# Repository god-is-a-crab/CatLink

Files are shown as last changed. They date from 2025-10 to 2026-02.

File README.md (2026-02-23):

# CatLink
This is a GPS tracking solution for cats.

## Overview

There are 3 components of the CatLink system:

- Tracker (collar) - This device tracks the animal's position
- Gateway - This device manages communication with the tracker and the user's phone
- CatLink app - Displays animal position, radio link quality and other information

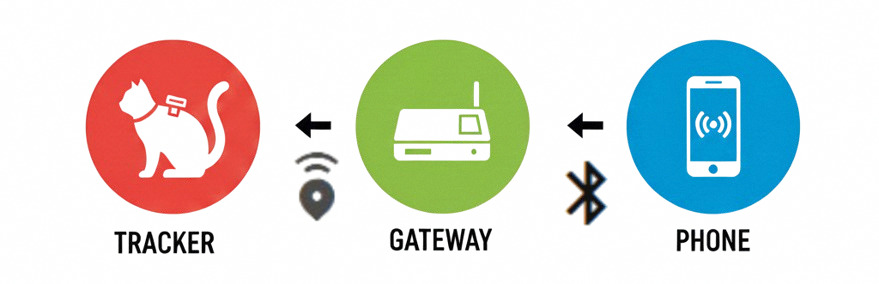
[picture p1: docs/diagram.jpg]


## Bluetooth Bonding
1. Open the app
2. When it tries to connect to the gateway, it will ask for a passkey to bond
3. Enter the number written on the gateway case
4. Close the app and open it again, the bluetooth connect button should show a green check mark

## How to use

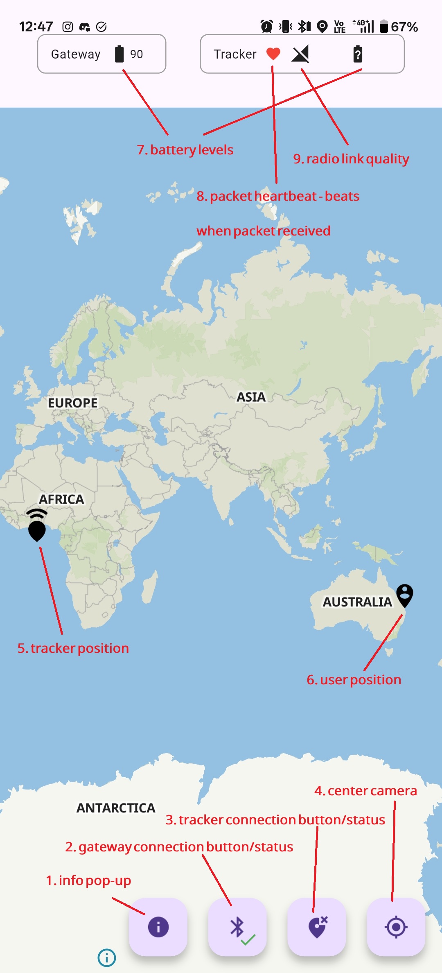
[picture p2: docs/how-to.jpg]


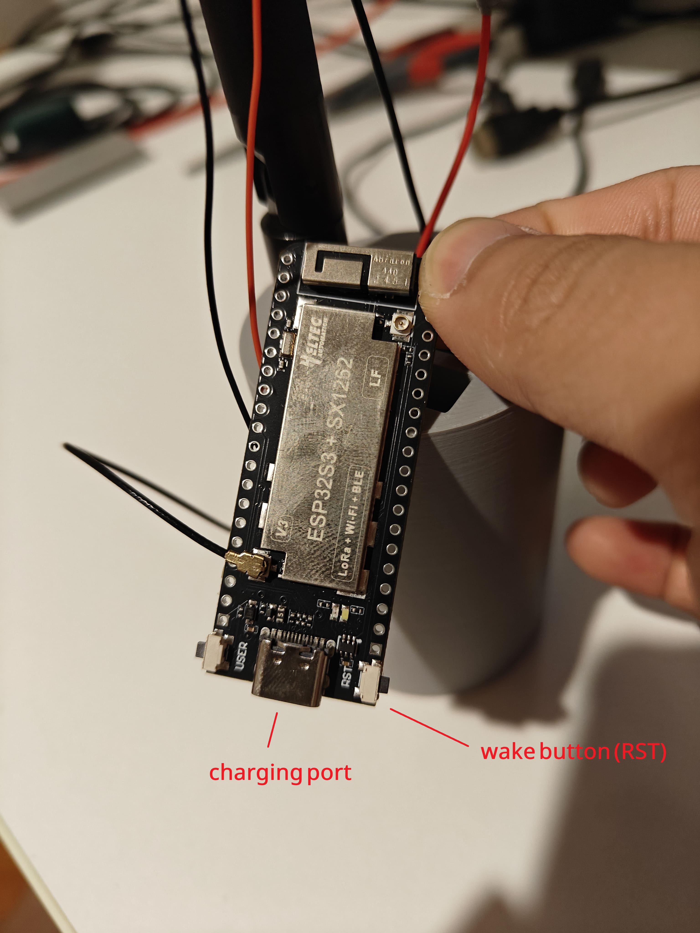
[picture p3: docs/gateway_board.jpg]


1. Wake up the gateway using the RST button, a white LED will flash to indicate the gateway is pending connection
2. On your phone, turn on location services and open the app
3. Monitor the bluetooth button (number 2 in image), wait for a green check mark to show
4. Press the tracker connect button (number 3 in image), wait for green check mark
5. Wait for tracker position marker (number 5 in image) to update
6. Monitor heartbeat symbol (number 8 in image) to confirm tracker is communicating

## Images

### Collar
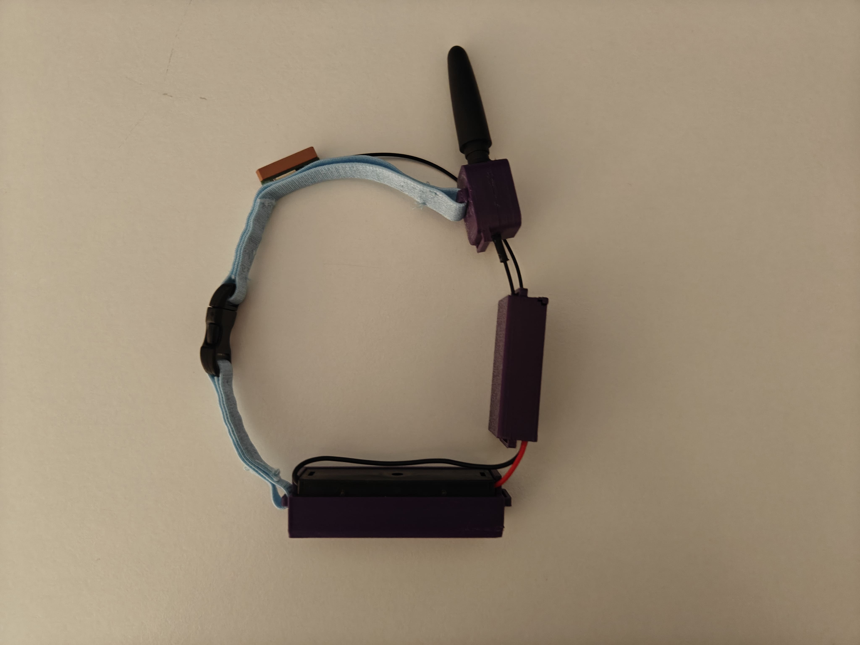
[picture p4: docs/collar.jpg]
collar


### Gateway
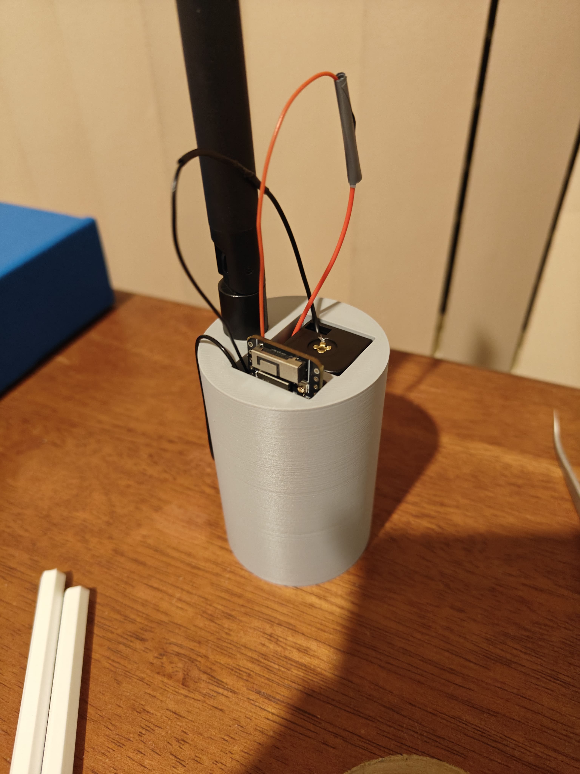
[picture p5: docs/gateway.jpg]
gateway


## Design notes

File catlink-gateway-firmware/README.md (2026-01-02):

## CatLink Gateway Firmware

CatLink gateway device which manages a LoRa connection to the tracker. Gateway is controlled by the app.

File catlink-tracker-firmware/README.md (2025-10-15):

# CatLink Tracker
This is a device that transmits GNSS position data to a receiver using an SX1268 LoRA module. It is optimized for low-power consumption.

## Pins
| IO Pin | MCU Function | Module Function |
|---|---|---|
| A0 | ADC1 C5 | Battery VIN |
| A2 | Output open-drain | Battery voltage divider switch |
| A4 | SPI1 NSS | LoRA NSS |
| A5 | SPI1 SCK | LoRA SCK |
| A6 | SPI1 MISO | LoRA MISO |
| A7 | SPI1 MOSI | LoRA MOSI |
| A15 | Input EXTI15_10 | DIO3 |
| B3 | Output | GNSS ON/OFF |
| B4 | Input EXTI4 | DIO1 |
| B5 | Input | GNSS 1PPS |
| B6 | USART1 TX | GNSS RX |
| B7 | USART1 RX | GNSS TX |

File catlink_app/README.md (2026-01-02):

# catlink_app

A mobile app to control the CatLink Gateway.

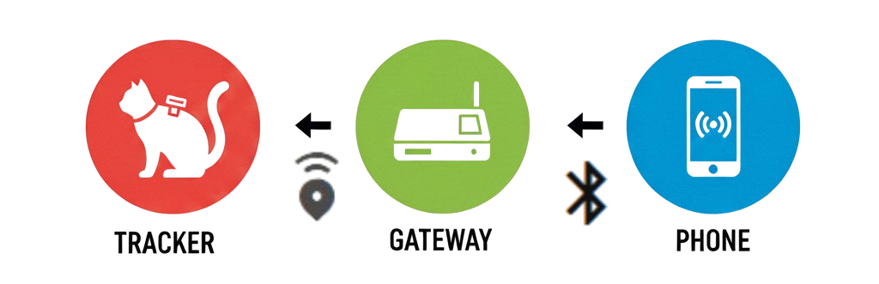
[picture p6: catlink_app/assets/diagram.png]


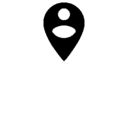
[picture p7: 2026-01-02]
catlink_app/assets/user_marker.png

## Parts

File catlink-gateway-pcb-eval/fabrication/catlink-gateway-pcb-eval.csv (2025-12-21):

Reference | Qty | Value | Footprint
BT1 | 1 | 18650 | Custom:BatteryHolder_Keystone_1042_1x18650
C1,C13 | 2 | 100n | Capacitor_SMD:C_0603_1608Metric
C2,C4,C6,C7,C8,C10,C11,C12 | 8 | 10u | Capacitor_SMD:C_0805_2012Metric
C3,C5,C9 | 3 | 1u | Capacitor_SMD:C_0603_1608Metric
D1,D2,D5 | 3 | ESD5Z6.0T1G | Diode_SMD:D_SOD-523
D3,D6 | 2 | GREEN | LED_SMD:LED_0805_2012Metric
D4,D8 | 2 | RED | LED_SMD:LED_0805_2012Metric
D7 | 1 | TPD1E0B04DPY | Custom:D_Texas_DPY0002A_0.6x1mm_P0.65mm
J1 | 1 | TYPE-C-31-M-12 | Connector_USB:USB_C_Receptacle_HRO_TYPE-C-31-M-12
J2,J3 | 2 | Conn_02x05_Odd_Even | Connector_PinHeader_2.54mm:PinHeader_2x05_P2.54mm_Vertical
R1,R2,R3,R9,R13,R14,R17,R22,R23 | 9 | 10k | Resistor_SMD:R_0603_1608Metric
R4,R5 | 2 | 22 | Custom:R_0603_1608Metric
R6,R7 | 2 | 5k1 | Resistor_SMD:R_0603_1608Metric
R8 | 1 | 400m | Resistor_SMD:R_1206_3216Metric
R10,R11,R12,R20,R21 | 5 | 1k2 | Resistor_SMD:R_0603_1608Metric
R15,R16,R19 | 3 | 330k | Resistor_SMD:R_0603_1608Metric
R18 | 1 | 1M5 | Resistor_SMD:R_0603_1608Metric
SW1,SW2 | 2 | SW_SPDT | Button_Switch_THT:SW_Slide_SPDT_Angled_CK_OS102011MA1Q
U1 | 1 | ESP32-C3-MINI-1 | Custom:ESP32-C3-MINI-1
U2 | 1 | TPD4E05U06DQA | Package_SON:USON-10_2.5x1.0mm_P0.5mm
U3 | 1 | TP4056-42-ESOP8 | Package_SO:SOIC-8-1EP_3.9x4.9mm_P1.27mm_EP2.41x3.3mm
U4 | 1 | TPS2116DRL | Package_TO_SOT_SMD:SOT-583-8
U5 | 1 | TLV75901PDRV | Package_SON:WSON-6-1EP_2x2mm_P0.65mm_EP1x1.6mm
U6 | 1 | Ai-Thinker-Ra-01S | Custom:Ai-Thinker-Ra-01S

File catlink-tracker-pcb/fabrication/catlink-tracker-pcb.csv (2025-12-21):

Reference | Qty | Value | Footprint
C1 | 1 | 4u7 | Custom:C_0603_1608Metric
C2,C3,C6,C10,C12,C13 | 6 | 100n | Custom:C_0603_1608Metric
C4 | 1 | 10n | Custom:C_0603_1608Metric
C5,C7,C8 | 3 | 1u | Custom:C_0603_1608Metric
C9,C11 | 2 | 10u | Custom:C_0805_2012Metric
C14 | 1 | 100p | Custom:C_0603_1608Metric
D1 | 1 | ESD5Z6.0T1G | Custom:D_SOD-523
D2,D3 | 2 | TPD1E0B04DPY | Custom:D_Texas_DPY0002A_0.6x1mm_P0.65mm
J1 | 1 | S2B-PH-K | Connector_JST:JST_PH_S2B-PH-K_1x02_P2.00mm_Horizontal
J2 | 1 | U.FL | Connector_Coaxial:U.FL_Hirose_U.FL-R-SMT-1_Vertical
L1 | 1 | 82n | Custom:L_0603_1608Metric
R1,R2,R3,R4 | 4 | 10k | Custom:R_0603_1608Metric
R5,R6 | 2 | 100r | Custom:R_0603_1608Metric
TP1,TP2,TP3 | 3 | TestPoint | Custom:TestPoint_THT_D1.4mm_Drill0.8mm
U1 | 1 | STM32L412K8Tx | Custom:LQFP-32_7x7mm_P0.8mm
U2 | 1 | TLV75530PDBV | Custom:SOT-23-5
U3 | 1 | Ai-Thinker-Ra-01S | Custom:Ai-Thinker-Ra-01S
U4 | 1 | E108-GN03 | Custom:E108-GN03

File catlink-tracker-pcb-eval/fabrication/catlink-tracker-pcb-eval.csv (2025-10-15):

Id | Designator | Footprint | Quantity | Designation | Supplier and ref
1 | D2,D3 | D_Texas_DPY0002A_0.6x1mm_P0.65mm | 2 | TPD1E0B04DPY
2 | C8,C7,C5 | C_0603_1608Metric | 3 | 1u
3 | C9,C11 | C_0805_2012Metric | 2 | 10u
4 | C10,C3,C2,C13,C12,C6 | C_0603_1608Metric | 6 | 100n
5 | U2 | SOT-23-5 | 1 | TLV75530PDBV
6 | D1 | D_SOD-523 | 1 | ESD5Z6.0T1G
7 | U3 | Ai-Thinker-Ra-01S | 1 | Ai-Thinker-Ra-01S
8 | J4 | PinHeader_2x02_P2.54mm_Vertical | 1 | Header_02x02
9 | U4 | E108-GN03 | 1 | E108-GN03
10 | R3,R4,R2,R1 | R_0603_1608Metric | 4 | 10k
11 | L1 | L_0603_1608Metric | 1 | 82n
12 | J1 | JST_PH_S2B-PH-K_1x02_P2.00mm_Horizontal | 1 | S2B-PH-K
13 | J2 | U.FL_Hirose_U.FL-R-SMT-1_Vertical | 1 | U.FL
14 | C14 | C_0603_1608Metric | 1 | 100p
15 | C4 | C_0603_1608Metric | 1 | 10n
16 | R5,R6 | R_0603_1608Metric | 2 | 100r
17 | J8 | PinHeader_1x05_P2.54mm_Vertical | 1 | Header_01x05
18 | R8,R7 | R_Axial_DIN0204_L3.6mm_D1.6mm_P1.90mm_Vertical | 2 | 2k
19 | C1 | C_0603_1608Metric | 1 | 4u7
20 | D5 | LED_D3.0mm | 1 | RED
21 | D4 | LED_D3.0mm | 1 | BLUE
22 | J6 | PinHeader_1x02_P2.54mm_Vertical | 1 | Header_01x02
23 | J3 | PinHeader_1x04_P2.54mm_Vertical | 1 | Header_01x03
24 | J7 | PinHeader_1x06_P2.54mm_Vertical | 1 | Header_01x06
25 | U1 | LQFP-32_7x7mm_P0.8mm | 1 | STM32L412K8Tx
26 | J5 | PinHeader_2x03_P2.54mm_Vertical | 1 | Header_02x03
27 | SW1 | SW_PUSH_5x7mm | 1 | SW_Push

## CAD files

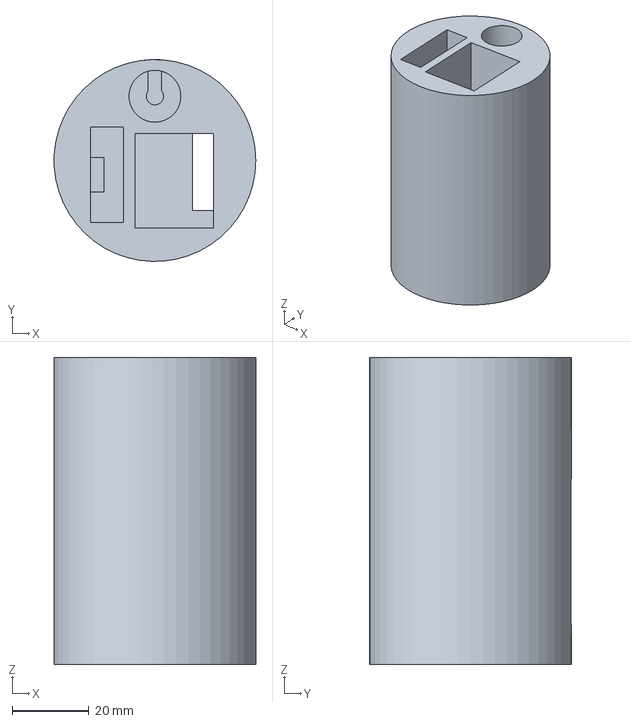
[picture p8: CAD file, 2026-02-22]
enclosures/gateway.FCStd
52.6 x 52.6 x 80.0 mm

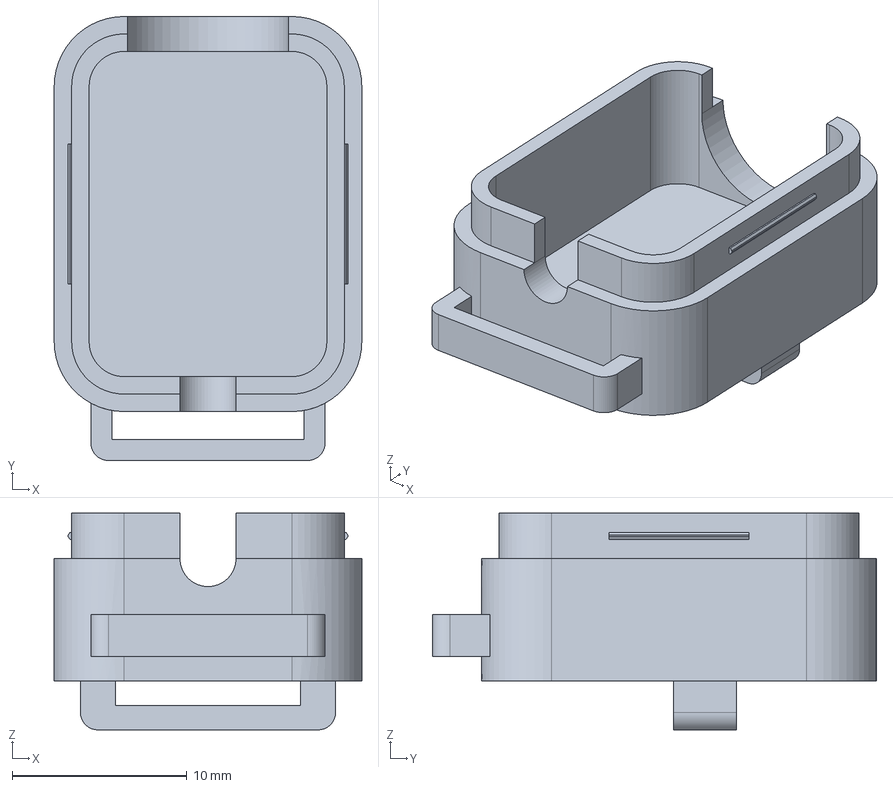
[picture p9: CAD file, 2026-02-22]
enclosures/lora_antenna.FCStd
17.6 x 25.4 x 12.4 mm

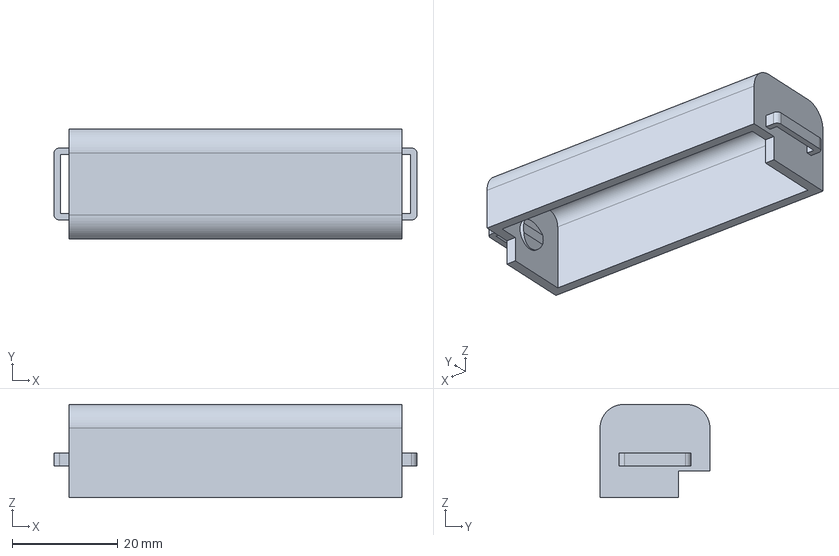
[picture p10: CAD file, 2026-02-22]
enclosures/battery14500.FCStd
68.6 x 20.8 x 17.6 mm

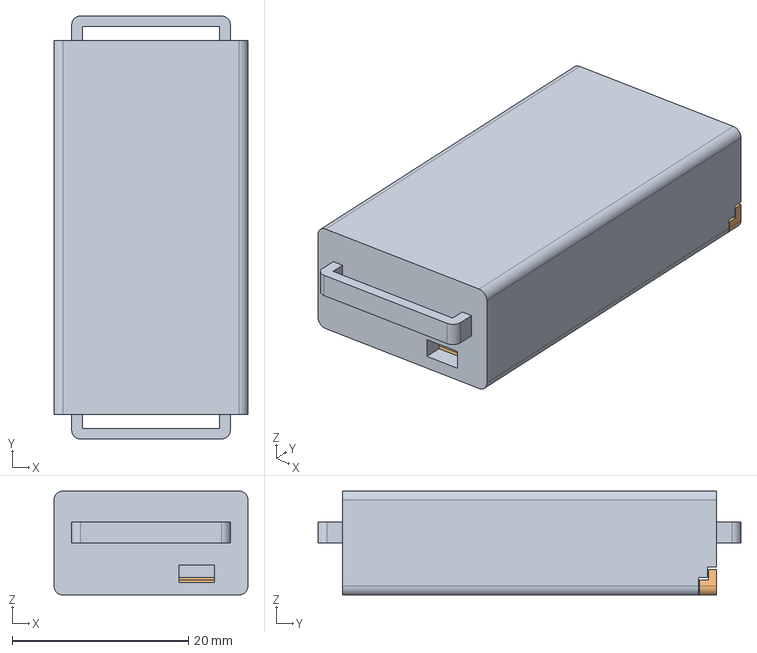
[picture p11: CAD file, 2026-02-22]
enclosures/pcb.FCStd
22.0 x 48.0 x 11.8 mm
enclosure
lid

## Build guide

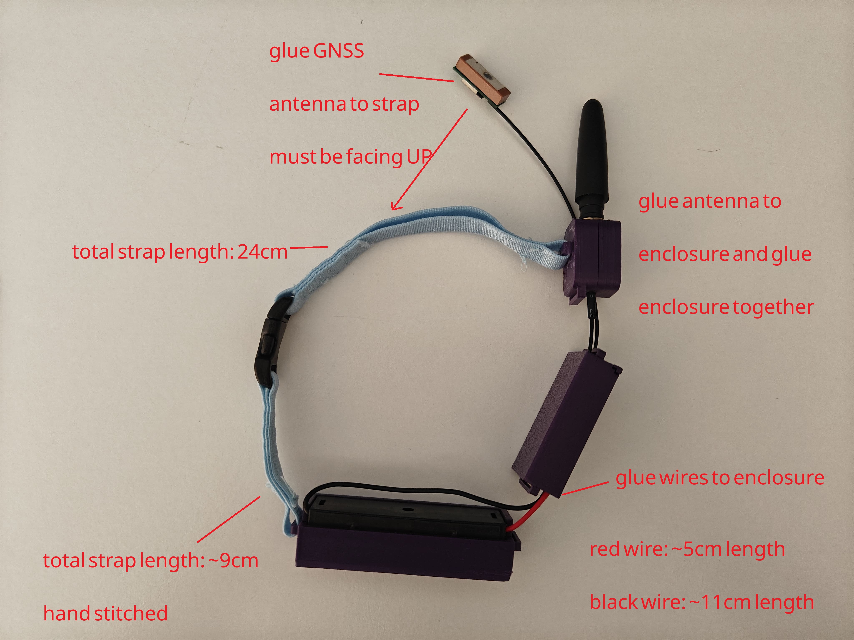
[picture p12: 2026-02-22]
docs/collar_assembly.jpg

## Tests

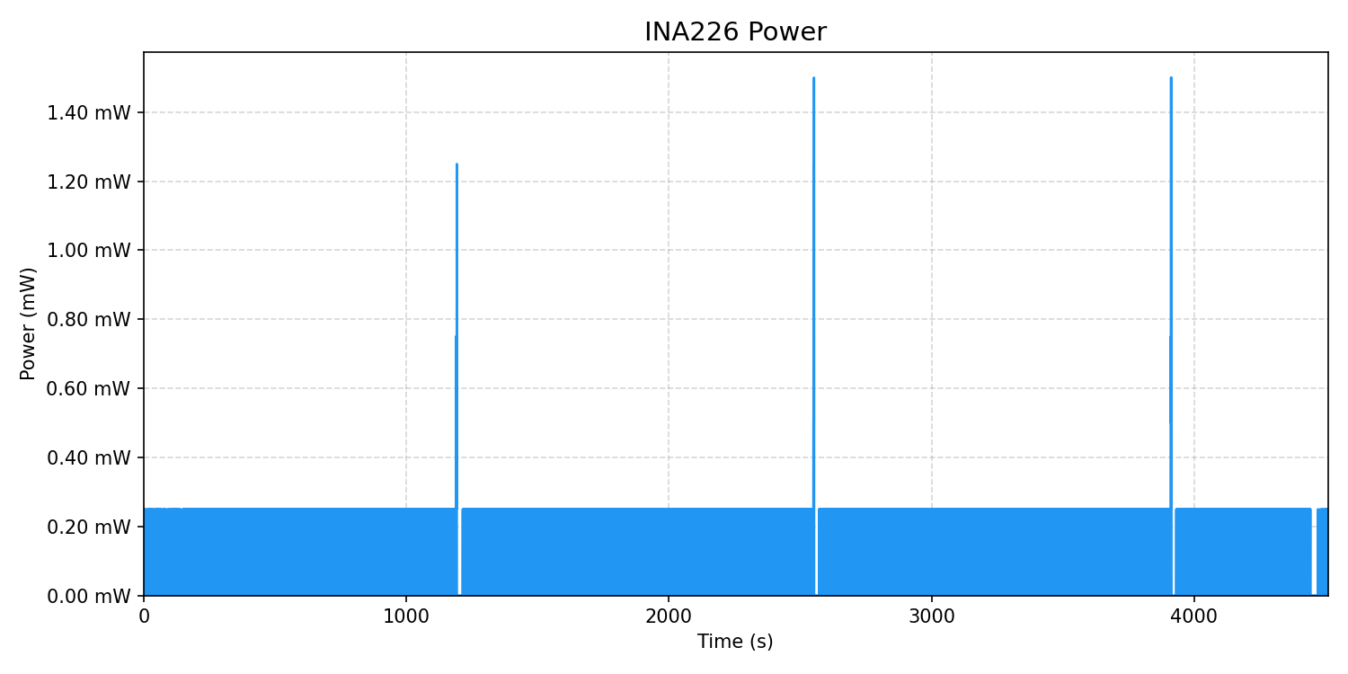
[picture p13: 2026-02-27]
power-measurement/v0.1-eval_sleep.png

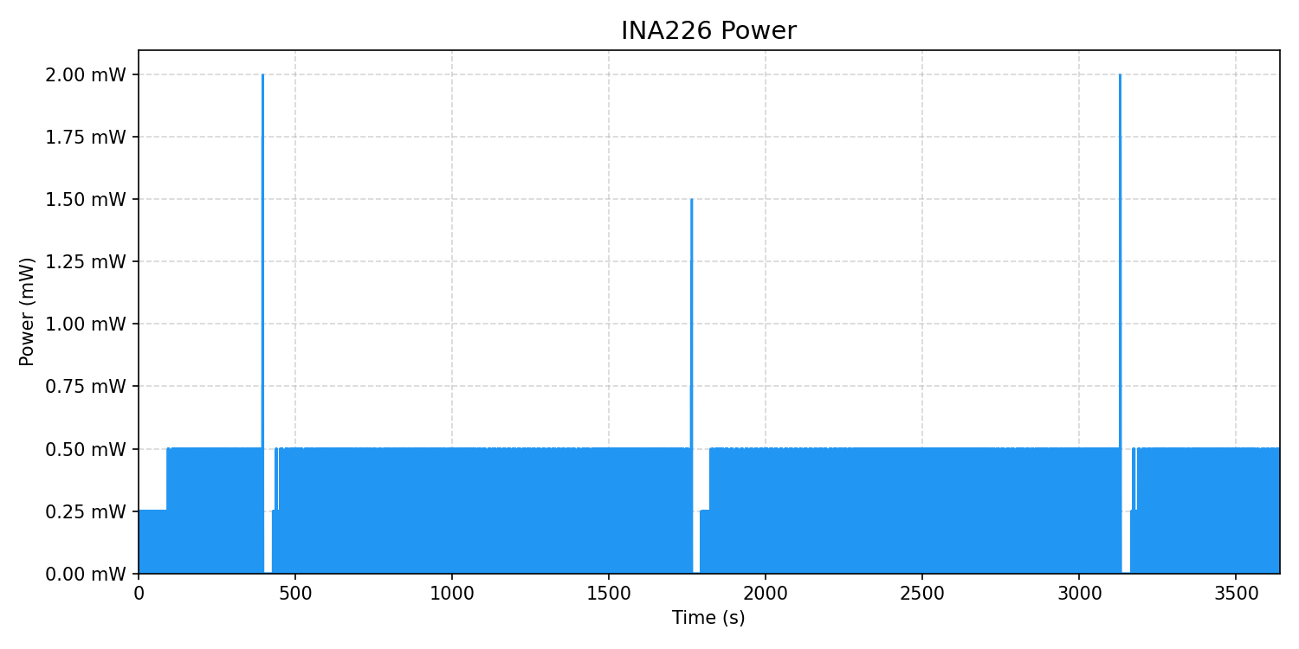
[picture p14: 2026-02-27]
power-measurement/v0.2-eval_sleep.png

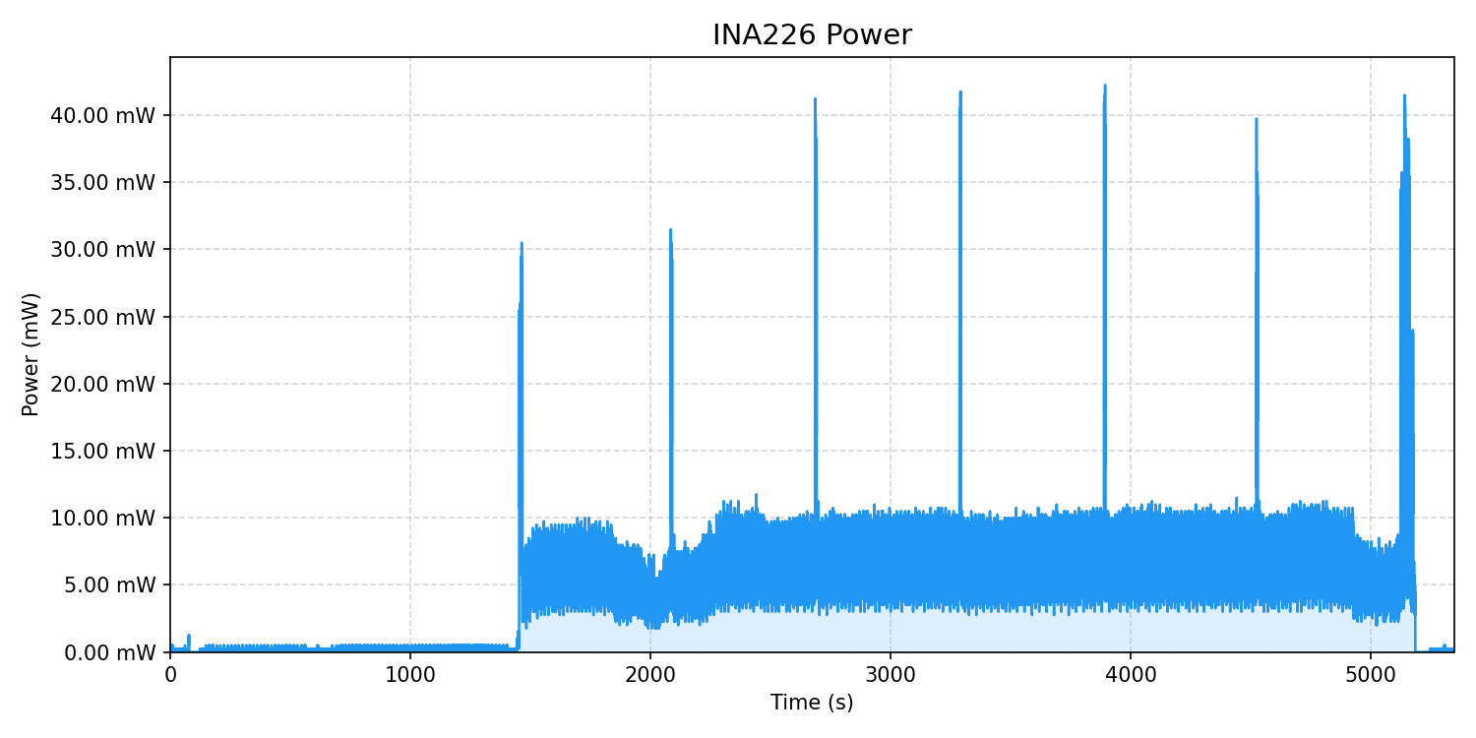
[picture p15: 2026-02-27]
power-measurement/v0.2-eval_tracking.png

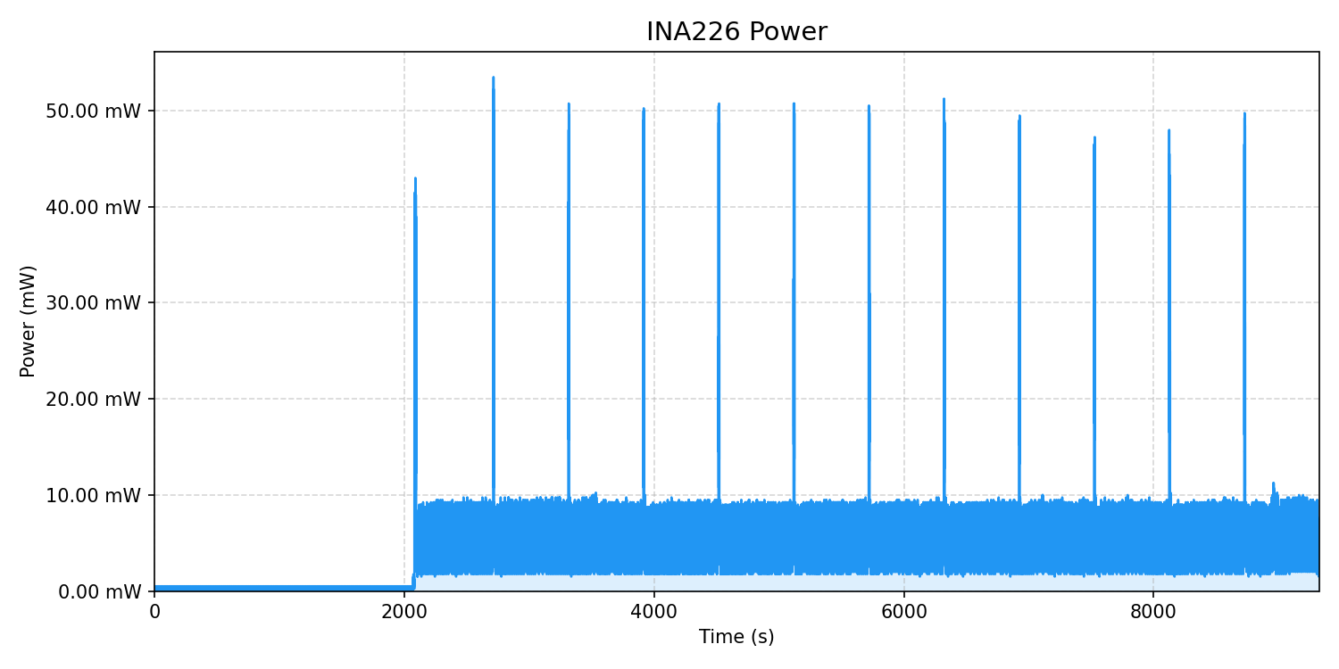
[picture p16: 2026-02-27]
power-measurement/prod_tracking_nofix.png

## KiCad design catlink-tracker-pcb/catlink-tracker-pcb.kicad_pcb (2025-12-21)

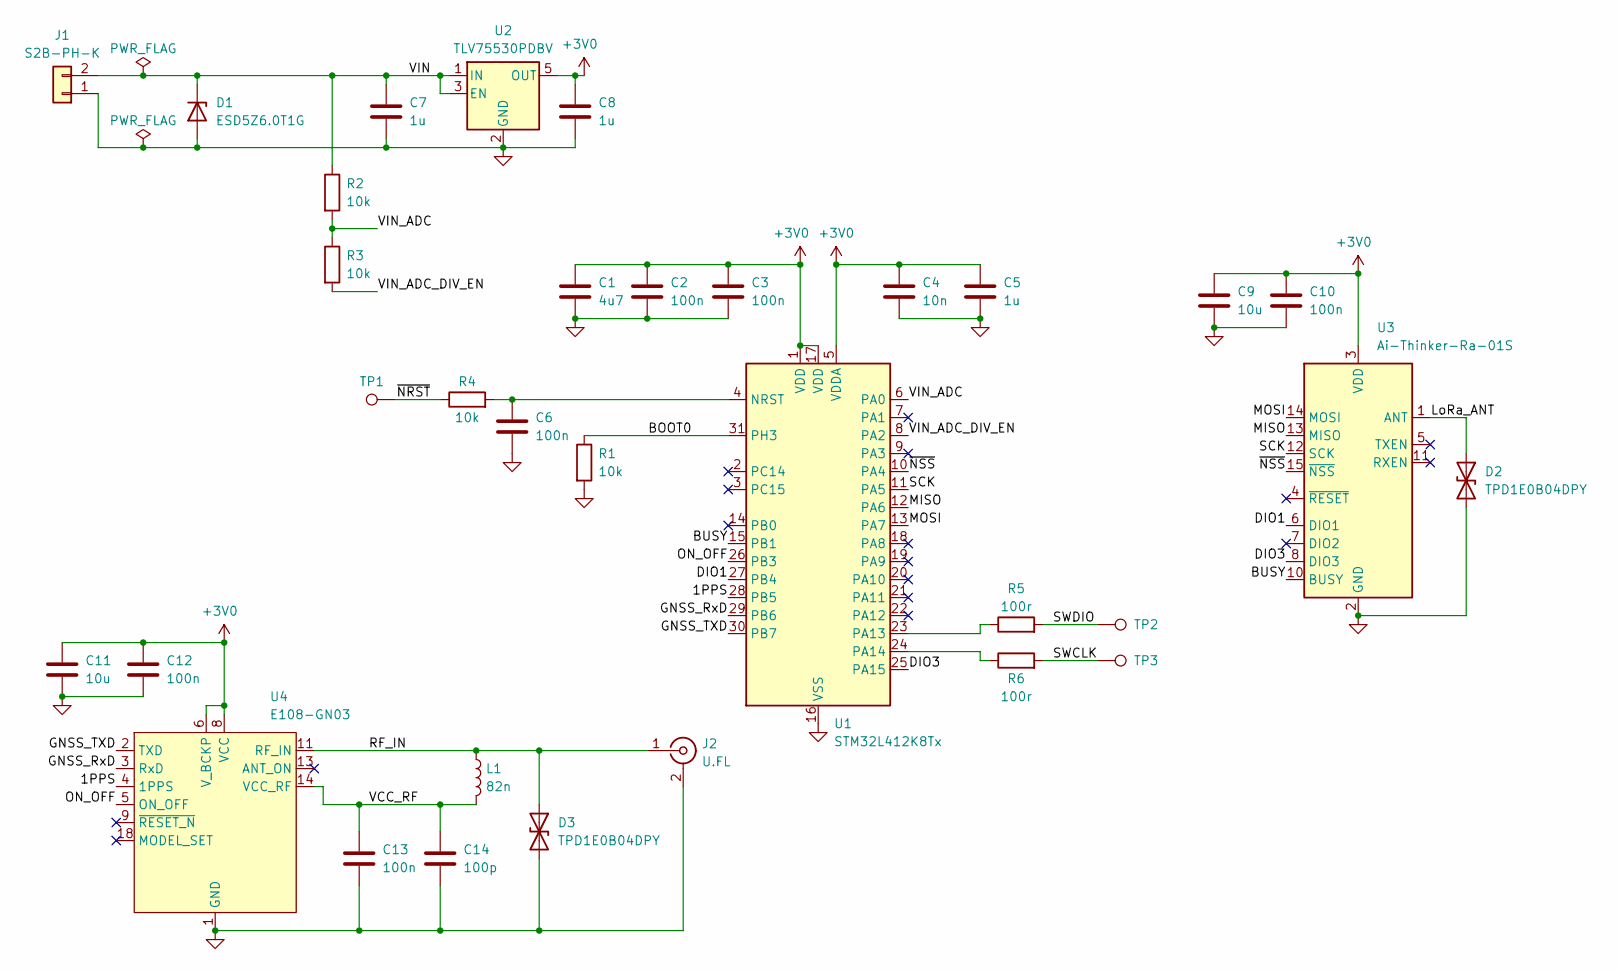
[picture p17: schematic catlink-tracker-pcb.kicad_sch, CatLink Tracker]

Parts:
C1: 4u7; C_0603_1608Metric
C2, C3, C6, C10, C12, C13: 100n; C_0603_1608Metric
C4: 10n; C_0603_1608Metric
C5, C7, C8: 1u; C_0603_1608Metric
C9, C11: 10u; C_0805_2012Metric
C14: 100p; C_0603_1608Metric
D1: ESD5Z6.0T1G; D_SOD-523
D2, D3: TPD1E0B04DPY; D_Texas_DPY0002A_0.6x1mm_P0.65mm
J1: S2B-PH-K; JST_PH_S2B-PH-K_1x02_P2.00mm_Horizontal
J2: U.FL; U.FL_Hirose_U.FL-R-SMT-1_Vertical
L1: 82n; L_0603_1608Metric
R1, R2, R3, R4: 10k; R_0603_1608Metric
R5, R6: 100r; R_0603_1608Metric
TP1, TP2, TP3: TestPoint; TestPoint_THT_D1.4mm_Drill0.8mm
U1: STM32L412K8Tx; LQFP-32_7x7mm_P0.8mm
U2: TLV75530PDBV; SOT-23-5
U3: Ai-Thinker-Ra-01S
U4: E108-GN03

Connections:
+3V0: C1.1, C2.1, C3.1, C4.1, C5.1, C8.1, C9.1, C10.1, C11.1, C12.1, U1.1 (VDD), U1.5 (VDDA), U1.17 (VDD), U2.5 (OUT), U3.3 (VDD), U4.6 (V_BCKP), U4.8 (VCC)
/1PPS: U1.28 (PB5), U4.4 (1PPS)
/BOOT0: R1.1, U1.31 (PH3)
/BUSY: U1.15 (PB1), U3.10 (BUSY)
/DIO1: U1.27 (PB4), U3.6 (DIO1)
/DIO3: U1.25 (PA15), U3.8 (DIO3)
/GNSS_RxD: U1.29 (PB6), U4.3 (RxD)
/GNSS_TXD: U1.30 (PB7), U4.2 (TXD)
/LoRa_ANT: D2.1 (A1), U3.1 (ANT)
/MISO: U1.12 (PA6), U3.13 (MISO)
/MOSI: U1.13 (PA7), U3.14 (MOSI)
/ON_OFF: U1.26 (PB3), U4.5 (ON_OFF)
/RF_IN: D3.1 (A1), J2.1 (In), L1.1, U4.11 (RF_IN)
/SCK: U1.11 (PA5), U3.12 (SCK)
/SWCLK: R6.2, TP3.1
/SWDIO: R5.2, TP2.1
/VCC_RF: C13.1, C14.1, L1.2, U4.14 (VCC_RF)
/VIN: C7.1, D1.1 (K), J1.2, R2.1, U2.1 (IN), U2.3 (EN)
/VIN_ADC: R2.2, R3.1, U1.6 (PA0)
/VIN_ADC_DIV_EN: R3.2, U1.8 (PA2)
/~NRST: R4.1, TP1.1
/~NSS: U1.10 (PA4), U3.15 (~NSS)
GND: C1.2, C2.2, C3.2, C4.2, C5.2, C6.2, C7.2, C8.2, C9.2, C10.2, C11.2, C12.2, C13.2, C14.2, D1.2 (A), D2.2 (A2), D3.2 (A2), J1.1, J2.2 (Ext), R1.2, U1.16 (VSS), U1.32 (VSS), U2.2 (GND), U3.2 (GND), U3.9 (GND), U3.16 (GND), U4.1 (GND), U4.10 (GND), U4.12 (GND)
unnamed: C6.1, R4.2, U1.4 (NRST)
unnamed: R5.1, U1.23 (PA13)
unnamed: R6.1, U1.24 (PA14)

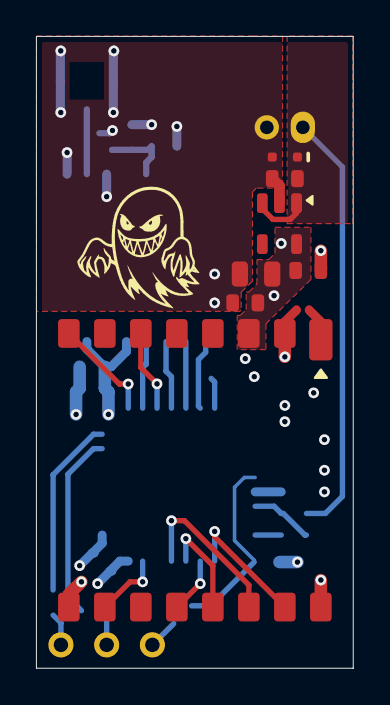
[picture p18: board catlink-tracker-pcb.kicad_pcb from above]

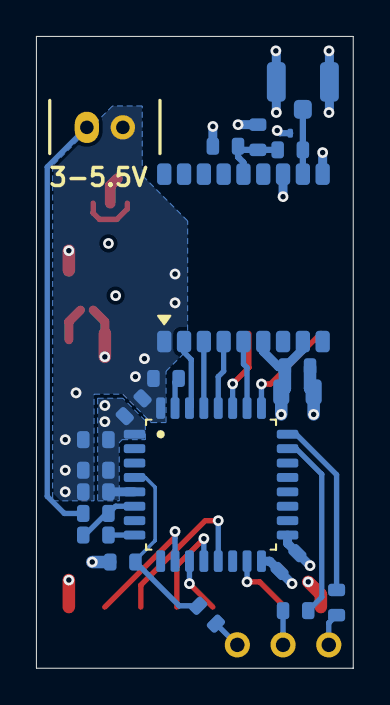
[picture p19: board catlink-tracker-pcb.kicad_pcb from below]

Board: 4 copper layers, 17.6 x 35.1 mm, 33 parts (25 on the bottom side), 26 nets.

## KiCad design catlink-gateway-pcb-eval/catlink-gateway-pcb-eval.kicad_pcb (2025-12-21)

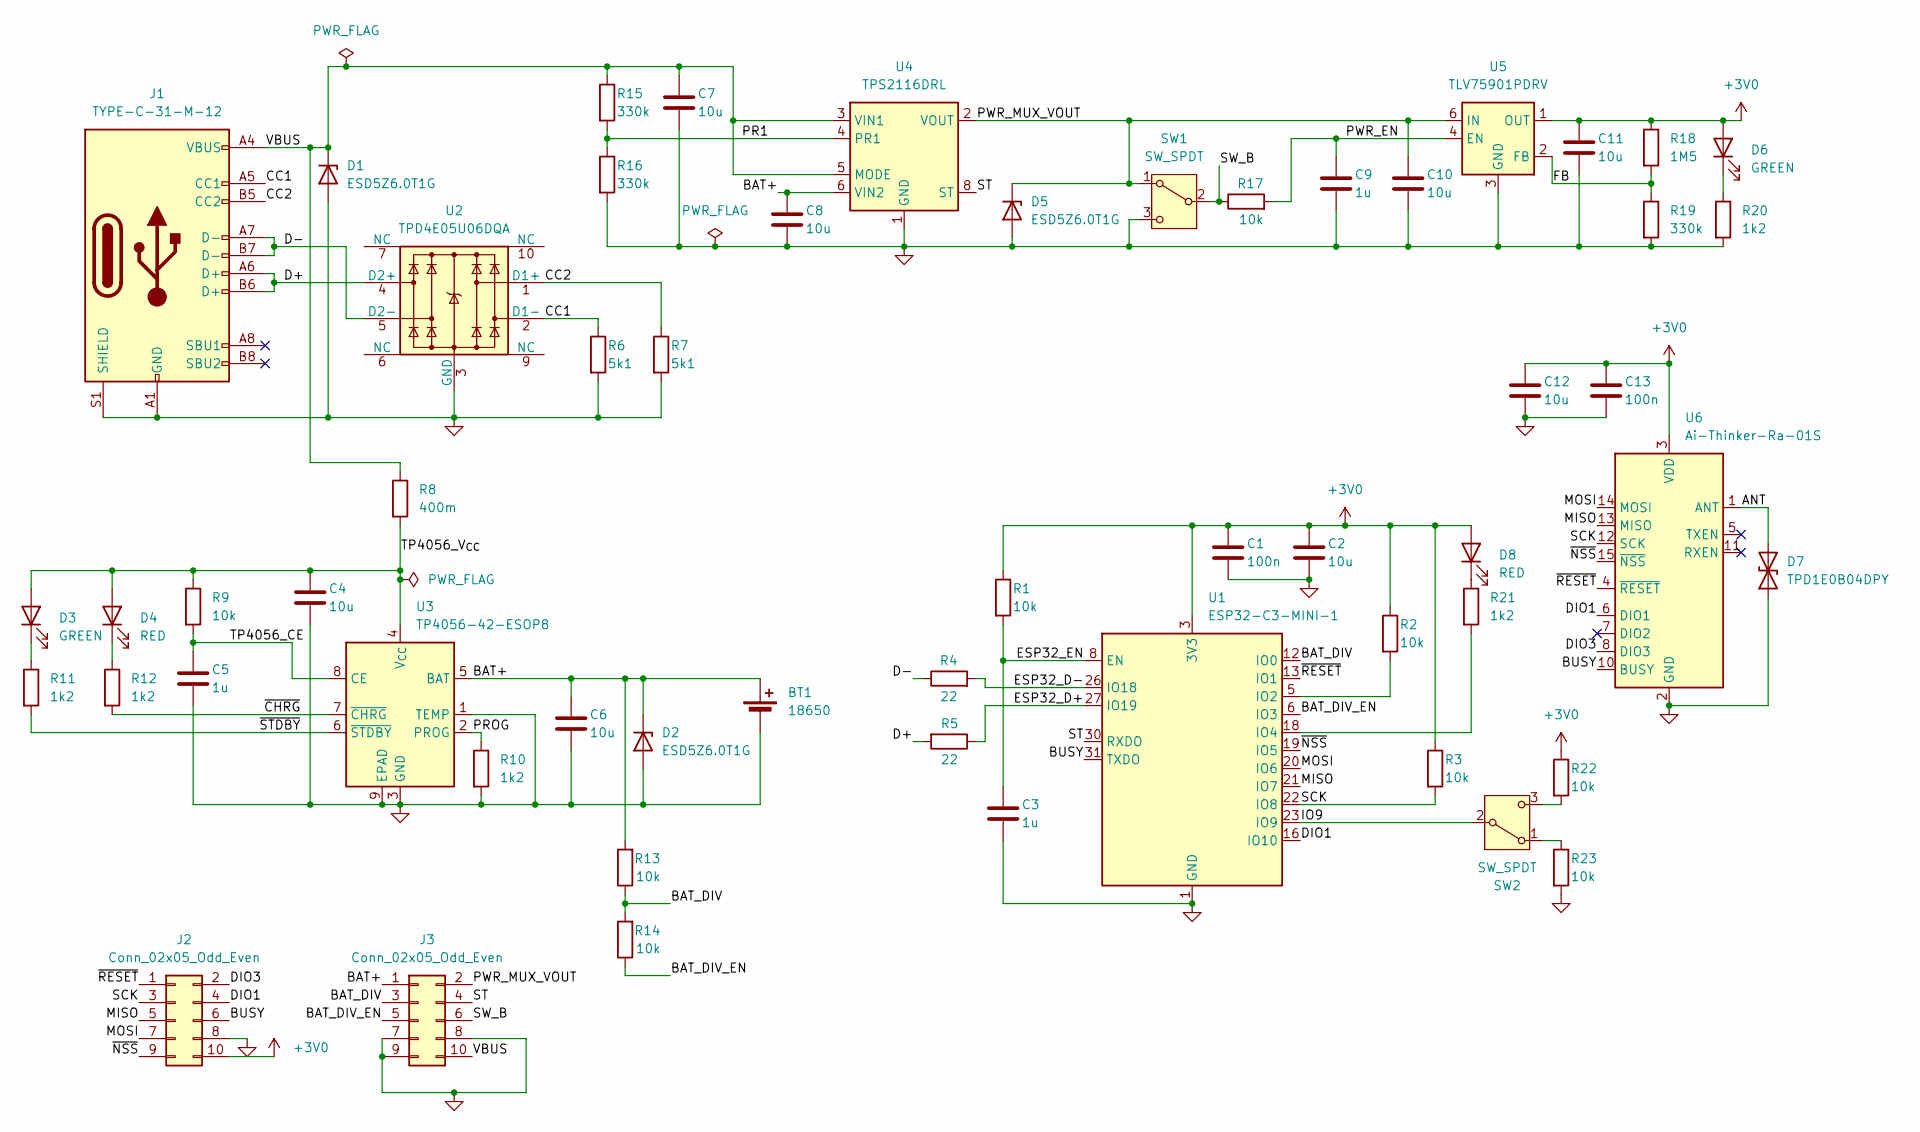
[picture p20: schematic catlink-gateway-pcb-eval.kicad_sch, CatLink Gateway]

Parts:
BT1: 18650; BatteryHolder_Keystone_1042_1x18650
C1, C13: 100n; C_0603_1608Metric
C2, C4, C6, C7, C8, C10, C11, C12: 10u; C_0805_2012Metric
C3, C5, C9: 1u; C_0603_1608Metric
D1, D2, D5: ESD5Z6.0T1G; D_SOD-523
D3, D6: GREEN; LED_0805_2012Metric
D4, D8: RED; LED_0805_2012Metric
D7: TPD1E0B04DPY; D_Texas_DPY0002A_0.6x1mm_P0.65mm
J1: TYPE-C-31-M-12; USB_C_Receptacle_HRO_TYPE-C-31-M-12
J2, J3: Conn_02x05_Odd_Even; PinHeader_2x05_P2.54mm_Vertical
R1, R2, R3, R9, R13, R14, R17, R22, R23: 10k; R_0603_1608Metric
R4, R5: 22; R_0603_1608Metric
R6, R7: 5k1; R_0603_1608Metric
R8: 400m; R_1206_3216Metric
R10, R11, R12, R20, R21: 1k2; R_0603_1608Metric
R15, R16, R19: 330k; R_0603_1608Metric
R18: 1M5; R_0603_1608Metric
SW1, SW2: SW_SPDT; SW_Slide_SPDT_Angled_CK_OS102011MA1Q
U1: ESP32-C3-MINI-1
U2: TPD4E05U06DQA; USON-10_2.5x1.0mm_P0.5mm
U3: TP4056-42-ESOP8; SOIC-8-1EP_3.9x4.9mm_P1.27mm_EP2.41x3.3mm
U4: TPS2116DRL; SOT-583-8
U5: TLV75901PDRV; WSON-6-1EP_2x2mm_P0.65mm_EP1x1.6mm
U6: Ai-Thinker-Ra-01S

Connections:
+3V0: C1.1, C2.1, C11.1, C12.1, C13.1, D6.2 (A), D8.2 (A), J2.10, R1.1, R2.1, R3.1, R18.1, R22.1, U1.3 (3V3), U5.1 (OUT), U6.3 (VDD)
/ANT: D7.2 (A2), U6.1 (ANT)
/BAT+: BT1.1 (+), C6.1, C8.1, D2.1 (K), J3.1, R13.2, U3.5 (BAT), U4.6 (VIN2)
/BAT_DIV: J3.3, R13.1, R14.2, U1.12 (IO0)
/BAT_DIV_EN: J3.5, R14.1, U1.6 (IO3)
/BUSY: J2.6, U1.31 (TXDO), U6.10 (BUSY)
/CC1: J1.A5 (CC1), R6.1, U2.2 (D1-)
/CC2: J1.B5 (CC2), R7.1, U2.1 (D1+)
/D+: J1.A6 (D+), J1.B6 (D+), R5.2, U2.4 (D2+)
/D-: J1.A7 (D-), J1.B7 (D-), R4.1, U2.5 (D2-)
/DIO1: J2.4, U1.16 (IO10), U6.6 (DIO1)
/DIO3: J2.2, U6.8 (DIO3)
/ESP32_D+: R5.1, U1.27 (IO19)
/ESP32_D-: R4.2, U1.26 (IO18)
/ESP32_EN: C3.1, R1.2, U1.8 (EN)
/FB: R18.2, R19.1, U5.2 (FB)
/IO9: SW2.2 (B), U1.23 (IO9)
/MISO: J2.5, U1.21 (IO7), U6.13 (MISO)
/MOSI: J2.7, U1.20 (IO6), U6.14 (MOSI)
/PR1: R15.2, R16.1, U4.4 (PR1)
/PROG: R10.1, U3.2 (PROG)
/PWR_EN: C9.1, R17.2, U5.4 (EN)
/PWR_MUX_VOUT: C10.1, D5.1 (K), J3.2, SW1.1 (A), U4.2 (VOUT), U4.7 (VOUT), U5.6 (IN)
/SCK: J2.3, R3.2, U1.22 (IO8), U6.12 (SCK)
/ST: J3.4, U1.30 (RXDO), U4.8 (ST)
/SW_B: J3.6, R17.1, SW1.2 (B)
/TP4056_CE: C5.1, R9.2, U3.8 (CE)
/TP4056_V_{CC}: C4.1, D3.2 (A), D4.2 (A), R8.2, R9.1, U3.4 (V_{CC})
/VBUS: C7.1, D1.1 (K), J1.A4 (VBUS), J1.A9 (VBUS), J1.B4 (VBUS), J1.B9 (VBUS), J3.10, R8.1, R15.1, U4.3 (VIN1), U4.5 (MODE)
/~CHRG: R12.2, U3.7 (~CHRG)
/~NSS: J2.9, U1.19 (IO5), U6.15 (~NSS)
/~RESET: J2.1, U1.13 (IO1), U6.4 (~RESET)
/~STDBY: R11.2, U3.6 (~STDBY)
GND: BT1.2 (-), C1.2, C2.2, C3.2, C4.2, C5.2, C6.2, C7.2, C8.2, C9.2, C10.2, C11.2, C12.2, C13.2, D1.2 (A), D2.2 (A), D5.2 (A), D7.1 (A1), J1.A1 (GND), J1.A12 (GND), J1.B1 (GND), J1.B12 (GND), J1.S1 (SHIELD), J2.8, J3.7, J3.8, J3.9, R6.2, R7.2, R10.2, R16.2, R19.2, R20.2, R23.2, SW1.3 (C), U1.1 (GND), U1.2 (GND), U1.11 (GND), U1.14 (GND), U1.36 (GND), U1.37 (GND), U1.38 (GND), U1.39 (GND), U1.40 (GND), U1.41 (GND), U1.42 (GND), U1.43 (GND), U1.44 (GND), U1.45 (GND), U1.46 (GND), U1.47 (GND), U1.48 (GND), U1.49 (GND), U1.50 (GND), U1.51 (GND), U1.52 (GND), U1.53 (GND), U2.3 (GND), U2.8 (GND), U3.1 (TEMP), U3.3 (GND), U3.9 (EPAD), U4.1 (GND), U5.3 (GND), U5.7 (GND), U6.2 (GND), U6.9 (GND), U6.16 (GND)
unnamed: D3.1 (K), R11.1
unnamed: D4.1 (K), R12.1
unnamed: D6.1 (K), R20.1
unnamed: D8.1 (K), R21.1
unnamed: R23.1, SW2.1 (A)
unnamed: R22.2, SW2.3 (C)
unnamed: R2.2, U1.5 (IO2)
unnamed: R21.2, U1.18 (IO4)

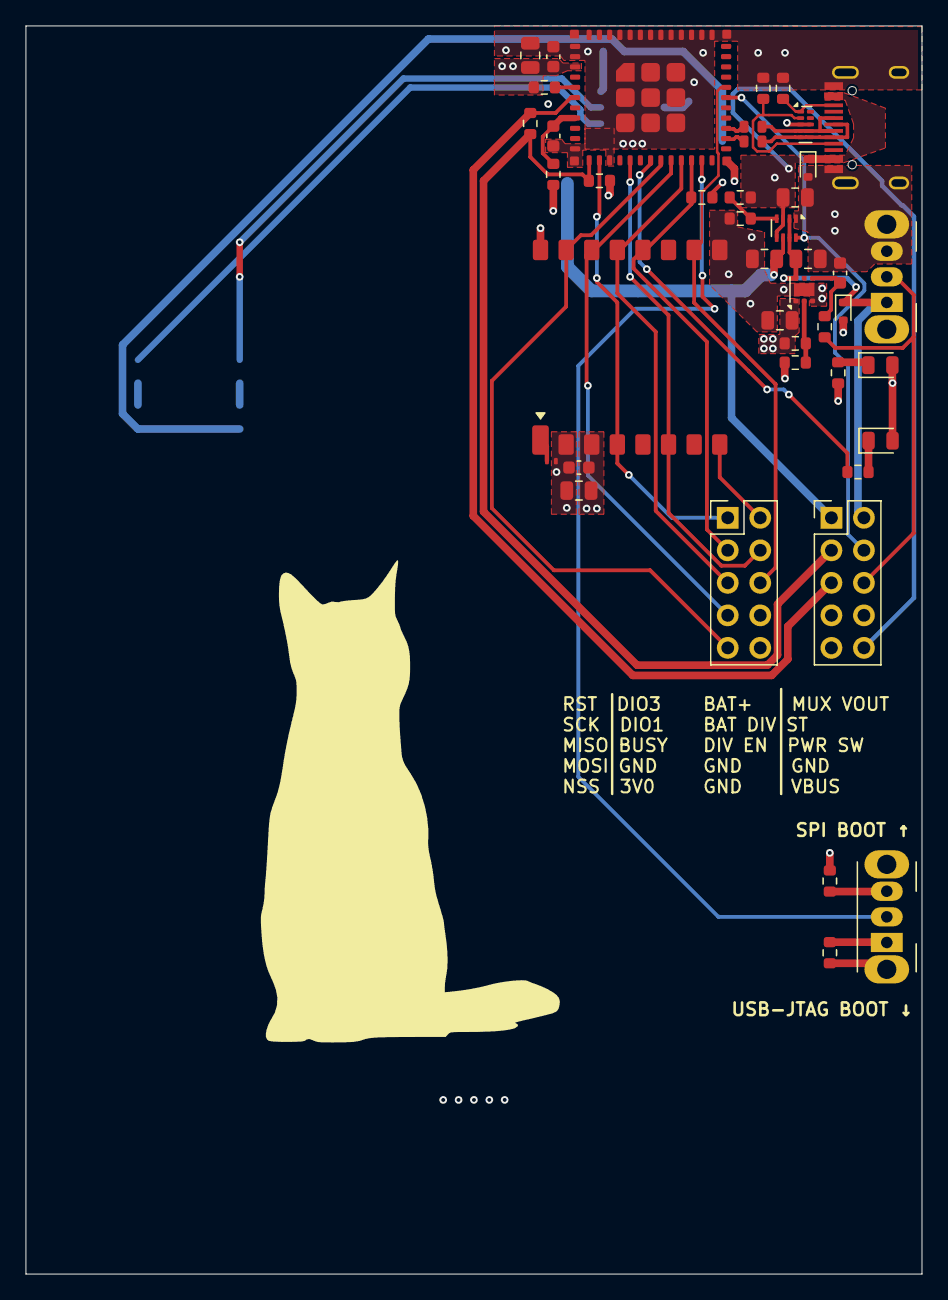
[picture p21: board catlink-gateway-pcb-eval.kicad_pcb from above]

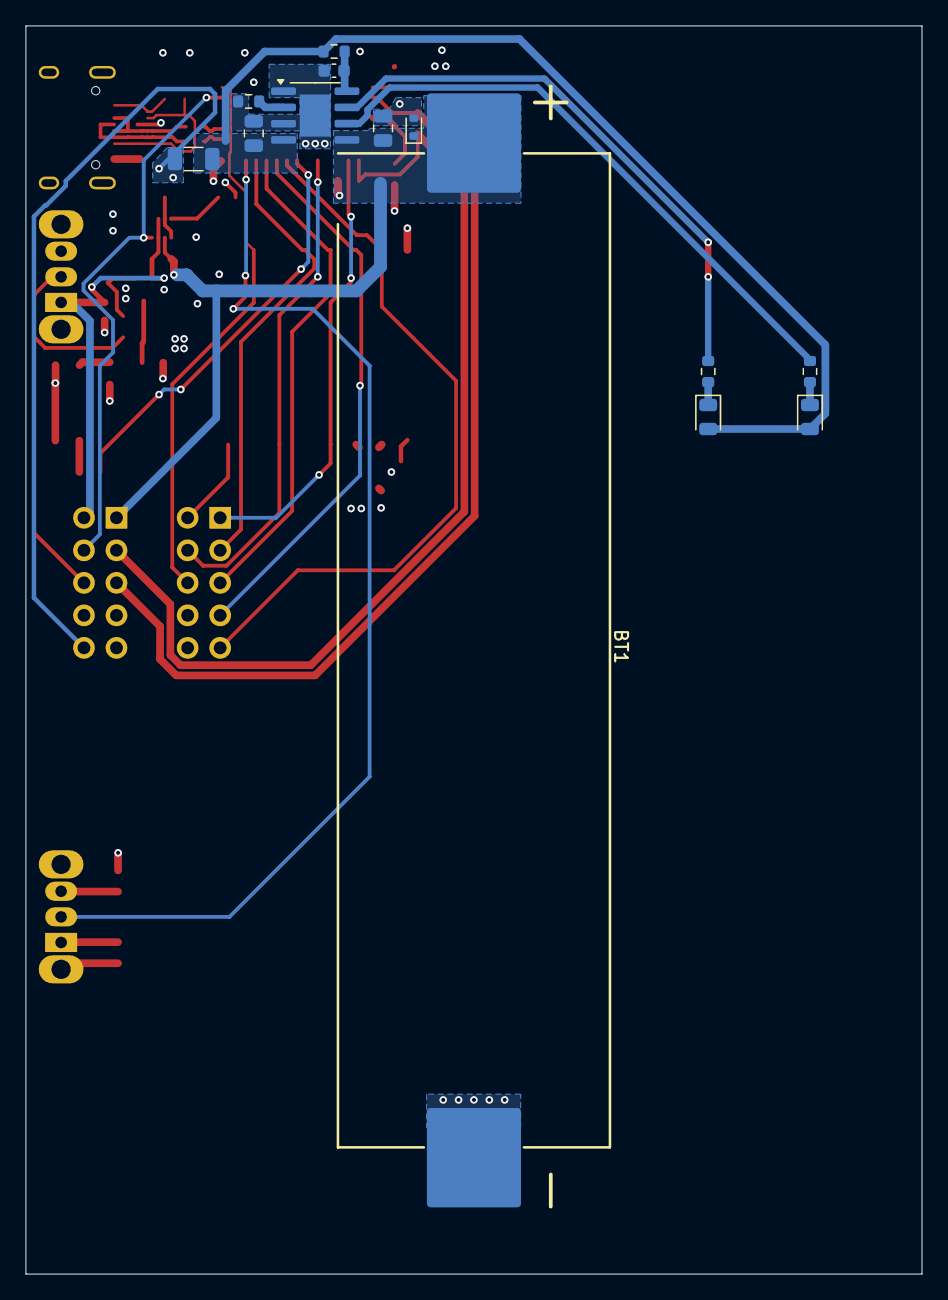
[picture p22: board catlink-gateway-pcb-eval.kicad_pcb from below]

Board: 4 copper layers, 70.0 x 97.5 mm, 56 parts (13 on the bottom side), 42 nets.

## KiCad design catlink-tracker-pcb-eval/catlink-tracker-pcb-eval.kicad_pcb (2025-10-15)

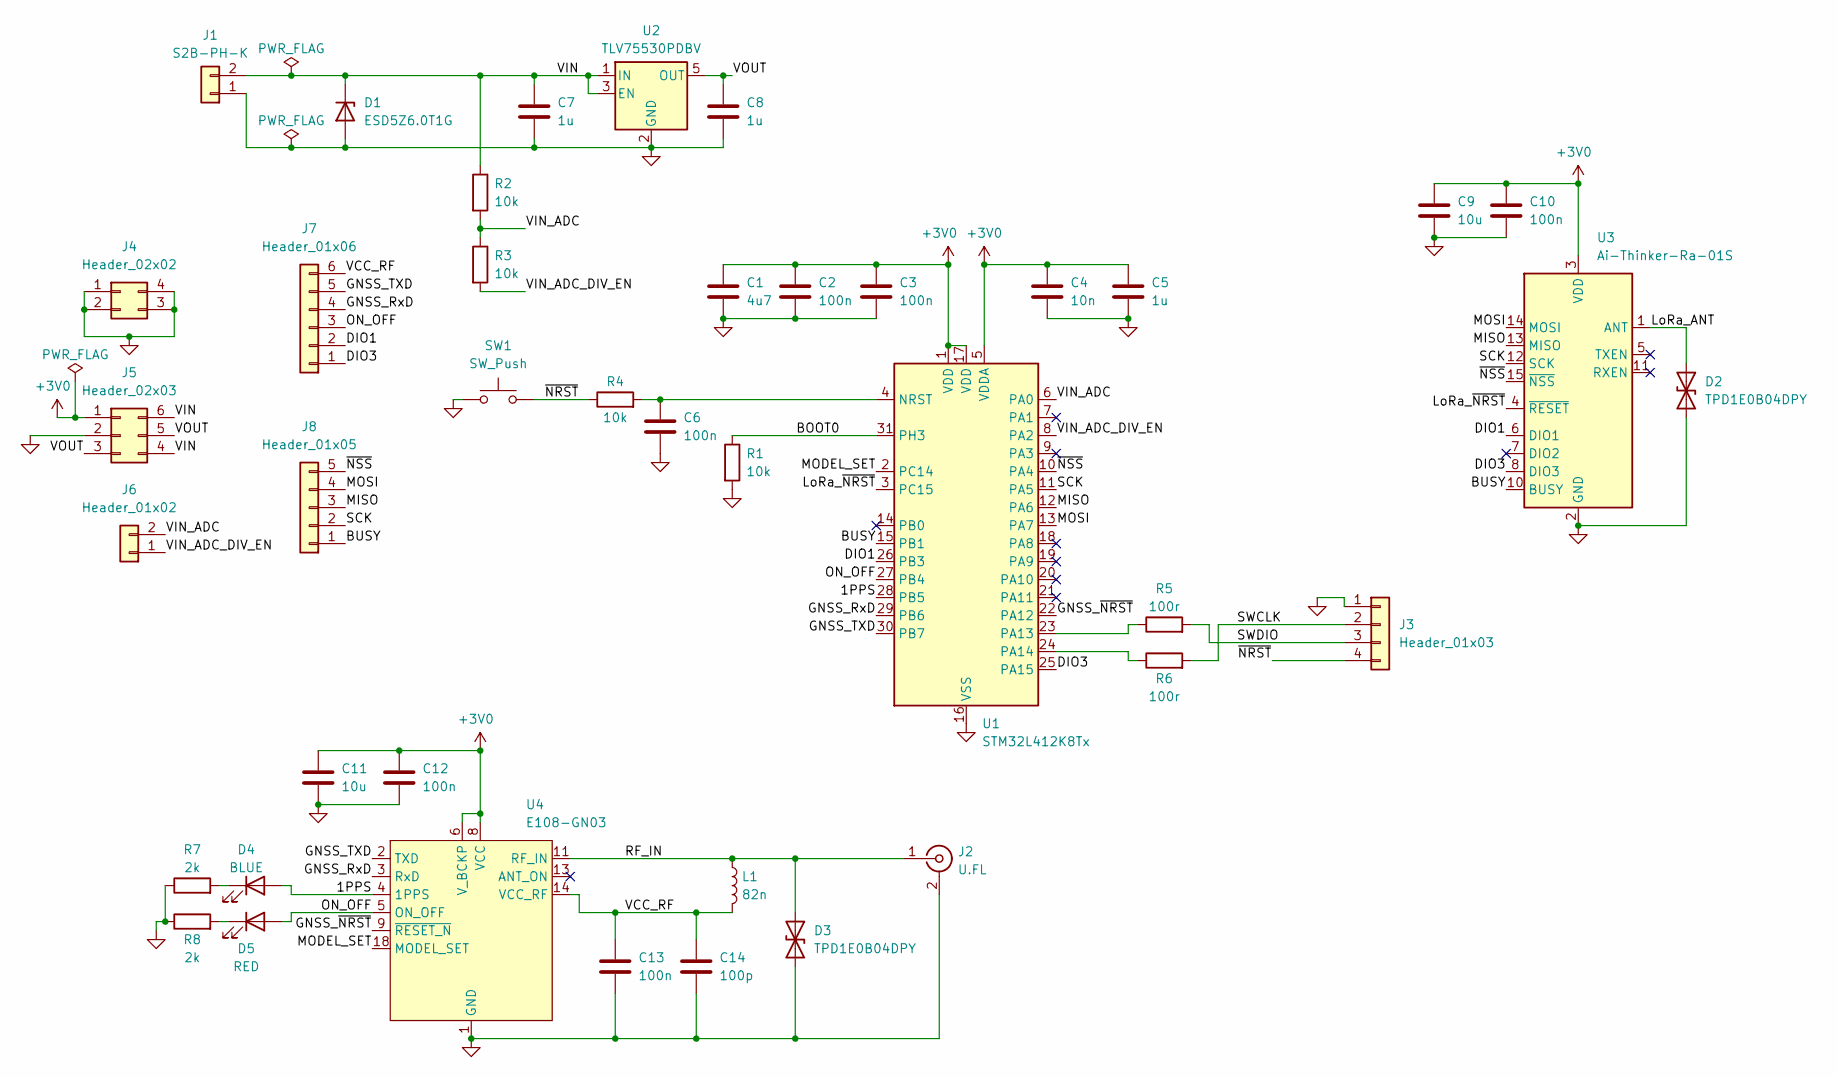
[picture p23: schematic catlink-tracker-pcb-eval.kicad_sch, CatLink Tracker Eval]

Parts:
C1: 4u7; C_0603_1608Metric
C2, C3, C6, C10, C12, C13: 100n; C_0603_1608Metric
C4: 10n; C_0603_1608Metric
C5, C7, C8: 1u; C_0603_1608Metric
C9, C11: 10u; C_0805_2012Metric
C14: 100p; C_0603_1608Metric
D1: ESD5Z6.0T1G; D_SOD-523
D2, D3: TPD1E0B04DPY; D_Texas_DPY0002A_0.6x1mm_P0.65mm
D4: BLUE; LED_D3.0mm
D5: RED; LED_D3.0mm
J1: S2B-PH-K; JST_PH_S2B-PH-K_1x02_P2.00mm_Horizontal
J2: U.FL; U.FL_Hirose_U.FL-R-SMT-1_Vertical
J3: Header_01x03; PinHeader_1x04_P2.54mm_Vertical
J4: Header_02x02; PinHeader_2x02_P2.54mm_Vertical
J5: Header_02x03; PinHeader_2x03_P2.54mm_Vertical
J6: Header_01x02; PinHeader_1x02_P2.54mm_Vertical
J7: Header_01x06; PinHeader_1x06_P2.54mm_Vertical
J8: Header_01x05; PinHeader_1x05_P2.54mm_Vertical
L1: 82n; L_0603_1608Metric
R1, R2, R3, R4: 10k; R_0603_1608Metric
R5, R6: 100r; R_0603_1608Metric
R7, R8: 2k; R_Axial_DIN0204_L3.6mm_D1.6mm_P1.90mm_Vertical
SW1: SW_Push; SW_PUSH_5x7mm
U1: STM32L412K8Tx; LQFP-32_7x7mm_P0.8mm
U2: TLV75530PDBV; SOT-23-5
U3: Ai-Thinker-Ra-01S
U4: E108-GN03

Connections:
+3V0: C1.1, C2.1, C3.1, C4.1, C5.1, C9.1, C10.1, C11.1, C12.1, J5.1, U1.1 (VDD), U1.5 (VDDA), U1.17 (VDD), U3.3 (VDD), U4.6 (V_BCKP), U4.8 (VCC)
/1PPS: D4.2 (A), U1.28 (PB5), U4.4 (1PPS)
/BOOT0: R1.1, U1.31 (PH3)
/BUSY: J8.1, U1.15 (PB1), U3.10 (BUSY)
/DIO1: J7.2, U1.26 (PB3), U3.6 (DIO1)
/DIO3: J7.1, U1.25 (PA15), U3.8 (DIO3)
/GNSS_RxD: J7.4, U1.29 (PB6), U4.3 (RxD)
/GNSS_TXD: J7.5, U1.30 (PB7), U4.2 (TXD)
/GNSS_~NRST: U1.22 (PA12), U4.9 (~RESET_N)
/LoRa_ANT: D2.1 (A1), U3.1 (ANT)
/LoRa_~NRST: U1.3 (PC15), U3.4 (~RESET)
/MISO: J8.3, U1.12 (PA6), U3.13 (MISO)
/MODEL_SET: U1.2 (PC14), U4.18 (MODEL_SET)
/MOSI: J8.4, U1.13 (PA7), U3.14 (MOSI)
/ON_OFF: D5.2 (A), J7.3, U1.27 (PB4), U4.5 (ON_OFF)
/RF_IN: D3.1 (A1), J2.1 (In), L1.1, U4.11 (RF_IN)
/SCK: J8.2, U1.11 (PA5), U3.12 (SCK)
/SWCLK: J3.2, R6.2
/SWDIO: J3.3, R5.2
/VCC_RF: C13.1, C14.1, J7.6, L1.2, U4.14 (VCC_RF)
/VIN: C7.1, D1.1 (K), J1.2, J5.4, J5.6, R2.1, U2.1 (IN), U2.3 (EN)
/VIN_ADC: J6.2, R2.2, R3.1, U1.6 (PA0)
/VIN_ADC_DIV_EN: J6.1, R3.2, U1.8 (PA2)
/VOUT: C8.1, J5.3, J5.5, U2.5 (OUT)
/~NRST: J3.4, R4.1, SW1.2
/~NSS: J8.5, U1.10 (PA4), U3.15 (~NSS)
GND: C1.2, C2.2, C3.2, C4.2, C5.2, C6.2, C7.2, C8.2, C9.2, C10.2, C11.2, C12.2, C13.2, C14.2, D1.2 (A), D2.2 (A2), D3.2 (A2), J1.1, J2.2 (Ext), J3.1, J4.1, J4.2, J4.3, J4.4, J5.2, R1.2, R7.1, R8.1, SW1.1, U1.16 (VSS), U1.32 (VSS), U2.2 (GND), U3.2 (GND), U3.9 (GND), U3.16 (GND), U4.1 (GND), U4.10 (GND), U4.12 (GND)
unnamed: D4.1 (K), R7.2
unnamed: D5.1 (K), R8.2
unnamed: C6.1, R4.2, U1.4 (NRST)
unnamed: R5.1, U1.23 (PA13)
unnamed: R6.1, U1.24 (PA14)

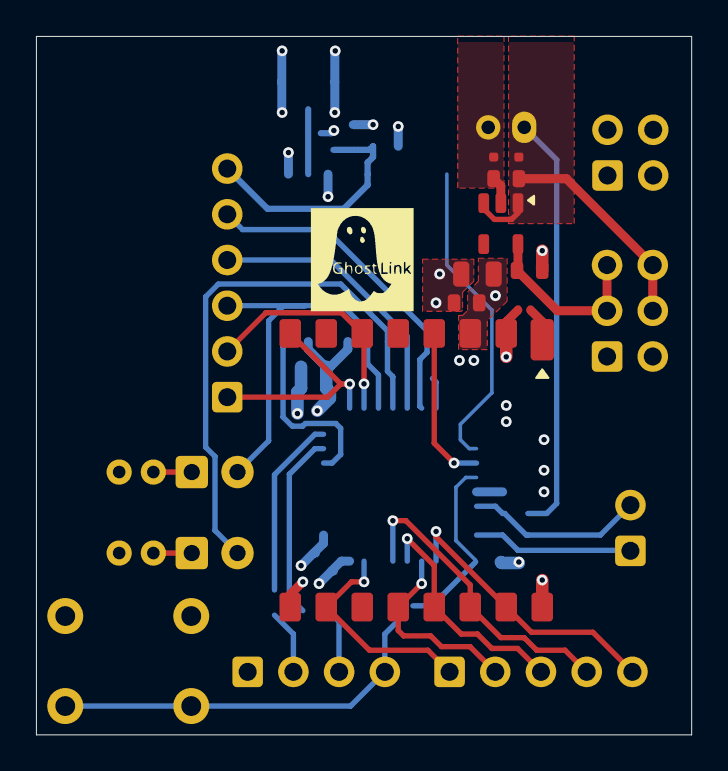
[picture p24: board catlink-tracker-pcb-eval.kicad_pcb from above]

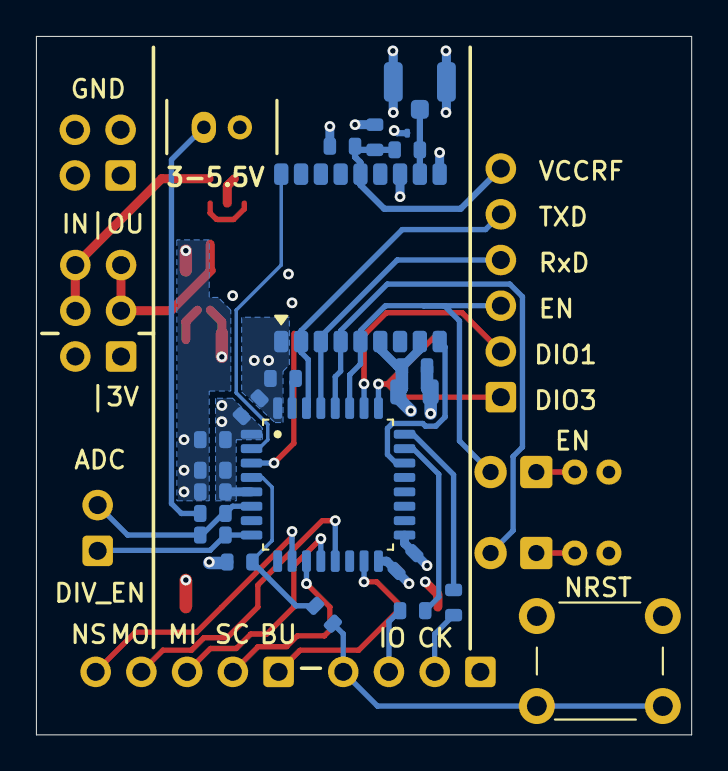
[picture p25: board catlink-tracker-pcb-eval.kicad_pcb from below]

Board: 4 copper layers, 36.4 x 38.8 mm, 41 parts (33 on the bottom side), 32 nets.

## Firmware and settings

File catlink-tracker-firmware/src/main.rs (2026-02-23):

#![no_std]
#![no_main]
#![allow(static_mut_refs)]

mod extract_gga;
mod sx126x;
mod sync_cell;

use core::{arch::asm, mem::MaybeUninit, panic::PanicInfo};
use cortex_m::Peripherals as CorePeripherals;
use cortex_m_rt::{entry, pre_init};
use extract_gga::{calculate_sentence_length, is_gga};
use static_fifo_queue::Queue;
use stm32l4::stm32l412::{Interrupt, Peripherals as DevicePeripherals, interrupt};
use sx126x::SyncSpiDescriptor;
use sync_cell::{SyncCell, SyncUnsafeCell};

// ==== Device configuration ====
/// Device address
const ADDRESS: u32 = 0x2BE45;
/// Whitelisted gateway address
const GATEWAY_ADDRESS: u32 = 0x0D121;
/// Wake-up interval in seconds
const WAKEUP_INTERVAL: u16 = 40;
/// Shutdown if divided battery voltage is lower than this.
/// Divider ratio = 0.5, Vref = 3V
const LOW_BATTERY_THRESHOLD: u8 = 0x81; // 0x81/0xFF * 3 * 2 = 3.04V
/// Maximum number of packet retries
const MAX_TX_RETRIES: u8 = 3;
/// Sample battery voltage every 12 hours
const SAMPLE_BAT_INTERVAL: u16 = 2160; // 86400 / 2 / 20

/// GNSS configuration - disable all sentences except GGA,
/// set GGA output to once every 9 update cycles
const GNSS_SET_SENTENCE_OUTPUT: [u8; 43] = *b"$PCAS03,9,0,0,0,0,0,0,0,0,0,,,0,0,,,,0*3B\r\n";

/// SLEEPDEEP 1, SLEEPONEXIT 1
const SLEEPDEEP_ON: u32 = 0b110;
/// SLEEPDEEP 0, SLEEPONEXIT 1
const SLEEPDEEP_OFF: u32 = 0b010;

// Peripheral register addresses for DMA
const SPI1_DR: u32 = 0x4001_300C;
const USART1_RDR: u32 = 0x4001_3824;
const USART1_TDR: u32 = 0x4001_3828;

/// Application state
static STATE: SyncCell<State> = SyncCell::new(State::Init);
/// Queue of SPI commands to run
static COMMANDS: SyncUnsafeCell<Queue<&SyncSpiDescriptor, 16>> = SyncUnsafeCell::new(Queue::new());
/// Circular buffer for GNSS NMEA data
static NMEA_BUFFER: SyncUnsafeCell<[u8; 1024]> = SyncUnsafeCell::new([0; 1024]);
/// The beginning of the current NMEA sentence in [`NMEA_BUFFER`]
static SENTENCE_BEGIN: SyncCell<usize> = SyncCell::new(0);
/// Last sampled divided battery voltage
static BAT_DIV_VOL: SyncCell<u8> = SyncCell::new(LOW_BATTERY_THRESHOLD);
/// TX power setting
static TX_POWER: SyncCell<TxPower> = SyncCell::new(TxPower::Dbm22);
/// Counter for doing things at intervals
static INTERVAL_COUNTER: SyncCell<u16> = SyncCell::new(0);

// Peripheral structs
static mut CORE_PERIPHERALS: MaybeUninit<CorePeripherals> = MaybeUninit::uninit();
static mut DEVICE_PERIPHERALS: MaybeUninit<DevicePeripherals> = MaybeUninit::uninit();

#[derive(Clone, Copy, PartialEq, Eq)]
enum State {
    Init,
    Sleep,
    ScanAdCad(bool), // Do 2 CADs
    ScanAdCadGetIrq(bool),
    ScanAdWaitingSynRx,
    ScanAdProcessSynRx,
    ScanAdSynAckTx(bool), // Send 2 SynAcks
    GnssContinue,
    GnssTx(u8), // u8: nth retry
    GnssWaitingAck(u8),
    GnssProcessAck(u8),
    SleepBegin,
    SleepContinue,
}

#[repr(u8)]
#[derive(Copy, Clone, PartialEq, Eq)]
enum TxPower {
    Dbm10 = 0,
    Dbm14 = 1,
    Dbm17 = 2,
    Dbm20 = 3,
    Dbm22 = 4,
}
impl TxPower {
    #[inline]
    const fn from_bits(bits: u8) -> Self {
        match bits {
            0 => Self::Dbm10,
            1 => Self::Dbm14,
            2 => Self::Dbm17,
            3 => Self::Dbm20,
            4 => Self::Dbm22,
            _ => Self::Dbm22,
        }
    }
    #[inline]
    const fn set_power(self) {
        let commands = COMMANDS.get_mut();
        match self {
            Self::Dbm10 => {
                commands.enqueue(&sx126x::SET_PA_CONFIG_10);
                commands.enqueue(&sx126x::SET_TX_PARAMS_15);
            }
            Self::Dbm14 => {
                commands.enqueue(&sx126x::SET_PA_CONFIG_14);
                commands.enqueue(&sx126x::SET_TX_PARAMS_15);
            }
            Self::Dbm17 => {
                commands.enqueue(&sx126x::SET_PA_CONFIG_17);
                commands.enqueue(&sx126x::SET_TX_PARAMS_22);
            }
            Self::Dbm20 => {
                commands.enqueue(&sx126x::SET_PA_CONFIG_20);
                commands.enqueue(&sx126x::SET_TX_PARAMS_22);
            }
            Self::Dbm22 => {
                commands.enqueue(&sx126x::SET_PA_CONFIG_22);
                commands.enqueue(&sx126x::SET_TX_PARAMS_22);
            }
        }
    }
    #[inline]
    fn adjust(self, tx_power_control_bits: u8) -> Self {
        match tx_power_control_bits {
            0 => self, // No change
            1 => {
                // Decrease
                if self == Self::Dbm10 {
                    // Already at lowest power, do nothing
                    self
                } else {
                    let new_tx_power = Self::from_bits(self as u8 - 1);
                    Self::set_power(new_tx_power);
                    new_tx_power
                }
            }
            2 => {
                // Increase
                if self == Self::Dbm22 {
                    // Already at highest power, do nothing
                    self
                } else {
                    let new_tx_power = Self::from_bits(self as u8 + 1);
                    Self::set_power(new_tx_power);
                    new_tx_power
                }
            }
            _ => self,
        }
    }
}

/// Initiates a sequence of SPI1 transfers over DMA1_CHANNEL2(RX) and DMA1_CHANNEL3(TX).
/// The sequence of commands starts with the command given to this function
/// and continues with commands from [`COMMANDS`] until no commands remain.
#[inline]
fn send_command(command: &SyncSpiDescriptor, dp: &mut DevicePeripherals) {
    // Write memory address for SPI1 RX DMA channel
    dp.DMA1.ch2().mar().write(|w| unsafe { w.ma().bits(command.0.rx_buf_ptr as u32) });
    // Write memory address for SPI1 TX DMA channel
    dp.DMA1.ch3().mar().write(|w| unsafe { w.ma().bits(command.0.tx_buf_ptr as u32) });

    // Set DMA transfer size for SPI1 RX/TX
    dp.DMA1.ch2().ndtr().write(|w| w.ndt().set(command.0.transfer_length));
    dp.DMA1.ch3().ndtr().write(|w| w.ndt().set(command.0.transfer_length));

    // Enable DMA for SPI1 RX, TX
    dp.DMA1.ch2().cr().write(|w| w.minc().set_bit().tcie().set_bit().en().set_bit());
    dp.DMA1.ch3().cr().write(|w| w.minc().set_bit().dir().from_memory().tcie().set_bit().en().set_bit());
    // Enable SPI1
    dp.SPI1.cr1().write(|w| w.mstr().set_bit().spe().enabled());
}

#[inline]
fn enter_stop2(cp: &mut CorePeripherals, dp: &mut DevicePeripherals) {
    unsafe {
        cp.SCB.scr.write(SLEEPDEEP_ON);
        // Prepare to enter Stop 2: enter run mode range 2 with Stop 2 selected
        dp.PWR.cr1().write(|w| w.vos().bits(2).lpr().clear_bit().lpms().bits(2).dbp().set_bit());
    }
    STATE.0.set(State::Sleep);
    while dp.PWR.sr2().read().reglpf().bit_is_set() {}
}

/// Switch GNSS module ON, begin receiving data and begin GNSS pre-init timer
#[inline]
fn gnss_on(dp: &mut DevicePeripherals) {
    dp.USART1.cr1().write(|w| w.cmie().set_bit().ue().set_bit().re().set_bit().te().set_bit());
    dp.DMA1.ch5().ndtr().write(|w| w.ndt().set(NMEA_BUFFER.get().len() as u16));
    dp.DMA1.ch5().cr().write(|w| w.minc().set_bit().circ().set_bit().en().set_bit());
    dp.GPIOB.bsrr().write(|w| w.bs3().set_bit());
    dp.TIM6.cr1().write(|w| w.urs().counter_only().opm().set_bit().cen().set_bit());
}

/// Switch GNSS module OFF and stop receiving data
#[inline]
fn gnss_off(dp: &mut DevicePeripherals) {
    dp.GPIOB.bsrr().write(|w| w.br3().set_bit());
    dp.DMA1.ch5().cr().write(|w| w.minc().set_bit().circ().set_bit().en().clear_bit());
    dp.USART1.cr1().write(|w| w.cmie().set_bit().ue().clear_bit().re().clear_bit());
}

#[inline]
fn start_adc(dp: &mut DevicePeripherals) {
    // Switch on battery voltage divider
    dp.GPIOA.bsrr().write(|w| w.br2().set_bit());
    // Power up ADC1
    dp.ADC1.cr().write(|w| w.deeppwd().clear_bit().advregen().set_bit());
    // See datasheet table 63 "ADC voltage regulator start-up time" p.115 (20 us)
    unsafe {
        asm!("nop"); // A single nop should be 5 us
        asm!("nop");
        asm!("nop");
        asm!("nop");
    }
    // ADC calibration p.383
    dp.ADC1.cr().write(|w| w.deeppwd().clear_bit().advregen().set_bit().adcal().set_bit());
    while dp.ADC1.cr().read().adcal().bit_is_set() {}
    // Enable ADC
    dp.ADC1.cr().write(|w| w.deeppwd().clear_bit().advregen().set_bit().aden().set_bit());
}

#[inline]
fn initiate_cad(dp: &mut DevicePeripherals) {
    COMMANDS.get_mut().enqueue(&sx126x::SET_CAD);
    STATE.0.set(State::ScanAdCad(true));
    send_command(&sx126x::SET_STANDBY, dp);
}

/// System reset on panic
#[inline(never)]
#[panic_handler]
fn panic_sys_reset(_info: &PanicInfo) -> ! {
    cortex_m::peripheral::SCB::sys_reset();
}

/// GNSS pre-init delay
#[interrupt]
fn TIM6_DACUNDER() {
    let dp = unsafe { DEVICE_PERIPHERALS.assume_init_mut() };

    // Configure GNSS
    dp.DMA1.ch4().ndtr().write(|w| w.ndt().set(GNSS_SET_SENTENCE_OUTPUT.len() as u16));
    dp.DMA1.ch4().cr().write(|w| w.minc().set_bit().dir().from_memory().tcie().set_bit().en().set_bit());

    dp.TIM6.sr().write(|w| w.uif().clear_bit());
}

/// When GNSS is ON, DMA1 CH5 is running in circular mode in the background.
/// This interrupt fires when the end of a NMEA sentence is detected.
#[interrupt]
fn USART1() {
    let dp = unsafe { DEVICE_PERIPHERALS.assume_init_mut() };
    let ndtr = dp.DMA1.ch5().ndtr().read().ndt().bits();
    let commands = COMMANDS.get_mut();

    dp.USART1.icr().write(|w| w.cmcf().clear_bit_by_one().orecf().clear_bit_by_one());

    // Sometimes the sentence is shifted by 1
    let sentence_begin_corrected = if unsafe { *NMEA_BUFFER.get().get_unchecked(SENTENCE_BEGIN.0.get()) } == b'$' {
        SENTENCE_BEGIN.0.get()
    } else {
        SENTENCE_BEGIN.0.get() + 1
    };
    // Update sentence position
    let sentence_length = calculate_sentence_length(ndtr, SENTENCE_BEGIN.0.get());
    SENTENCE_BEGIN.0.update(|s| (s + sentence_length) & (NMEA_BUFFER.get().len() - 1));

    if is_gga(NMEA_BUFFER.get(), sentence_begin_corrected) {
        unsafe {
            sx126x::PACKET.insert_position(NMEA_BUFFER.get(), sentence_begin_corrected);

            // Prepare packet header and transfer length
            sx126x::PACKET.set_header();

            commands.enqueue(&sx126x::WRITE_PACKET);
        }
        commands.enqueue(&sx126x::UNMASK_TXDONE);
        commands.enqueue(&sx126x::SET_TX);
        STATE.0.set(State::GnssTx(0));
        send_command(&sx126x::SET_PACKET_PARAMS, dp);
    }
}

/// Wake-up for CAD
#[interrupt]
fn RTC_WKUP() {
    let cp = unsafe { CORE_PERIPHERALS.assume_init_mut() };
    let dp = unsafe { DEVICE_PERIPHERALS.assume_init_mut() };

    dp.RTC.scr().write(|w| w.cwutf().set_bit());
    dp.EXTI.pr1().write(|w| w.pr20().clear_bit_by_one());

    unsafe {
        // Don't go back into Stop 2
        cp.SCB.scr.write(SLEEPDEEP_OFF);
        // Enter low-power run mode
        dp.PWR.cr1().write(|w| w.vos().bits(2).lpr().set_bit().lpms().bits(1).dbp().set_bit());
    }

    if INTERVAL_COUNTER.0.get() < SAMPLE_BAT_INTERVAL {
        INTERVAL_COUNTER.0.update(|c| c + 1);
        initiate_cad(dp);
    } else {
        INTERVAL_COUNTER.0.set(0);
        start_adc(dp);
    }
}

/// Sample divided battery voltage, if battery is too low, shutdown.
/// Otherwise, proceed with wake-up CAD sequence.
#[interrupt]
fn ADC1_2() {
    let cp = unsafe { CORE_PERIPHERALS.assume_init_mut() };
    let dp = unsafe { DEVICE_PERIPHERALS.assume_init_mut() };
    let isr = dp.ADC1.isr().read().bits();

    if isr & 1 == 1 {
        // ADC ready -> start ADC sample
        dp.ADC1.cr().write(|w| w.deeppwd().clear_bit().advregen().set_bit().aden().set_bit().adstart().set_bit());
        dp.ADC1.isr().write(|w| w.adrdy().clear_bit_by_one());
    } else if ((isr >> 2) & 1) == 1 {
        // EOC, conversion complete
        // Reading ADC1 DR resets EOC
        BAT_DIV_VOL.0.set(dp.ADC1.dr().read().rdata().bits() as u8);

        // Switch off battery divider
        dp.GPIOA.bsrr().write(|w| w.bs2().set_bit());
        // Disable and power down ADC1
        dp.ADC1.cr().write(|w| w.deeppwd().clear_bit().advregen().set_bit().aden().set_bit().addis().set_bit());
        while dp.ADC1.cr().read().aden().bit_is_set() {}
        dp.ADC1.cr().write(|w| w.deeppwd().set_bit());

        if BAT_DIV_VOL.0.get() < LOW_BATTERY_THRESHOLD {
            // Shutdown
            dp.RTC.cr().write(|w| w.wute().clear_bit()); // Disable wake-up timer
            dp.PWR.cr3().write(|w| w.apc().set_bit());
            // Pull-up NSS
            dp.PWR.pucra().write(|w| w.pu4().set_bit());
            // Pull-down GNSS ON/OFF
            dp.PWR.pdcrb().write(|w| w.pd3().set_bit());
            unsafe {
                cp.SCB.scr.write(SLEEPDEEP_ON);
                dp.PWR.cr1().write(|w| w.vos().bits(2).lpr().set_bit().lpms().bits(0b100).dbp().set_bit());
            }
        } else {
            initiate_cad(dp);
        }
    }
}
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
fn main() -> ! {
    let (cp, dp) = unsafe {
        (
            CORE_PERIPHERALS.write(CorePeripherals::take().unwrap()),
            DEVICE_PERIPHERALS.write(DevicePeripherals::take().unwrap()),
        )
    };

    // ==== RCC configuration ====
    // Set system clock speed to 200 kHz
    dp.RCC.cr().write(|w| w.msirange().range200k().msirgsel().set_bit());

    // Enable LSI for RTC
    dp.RCC.csr().write(|w| w.lsion().set_bit());

    // Enable peripheral clocks
    dp.RCC.ahb1enr().write(|w| w.dma1en().set_bit());
    dp.RCC.ahb2enr().write(|w| w.gpioaen().set_bit().gpioben().set_bit().adcen().set_bit());
    dp.RCC.apb1enr1().write(|w| w.pwren().set_bit().rtcapben().set_bit().tim6en().set_bit());
    dp.RCC.apb2enr().write(|w| w.syscfgen().set_bit().spi1en().set_bit().usart1en().set_bit());

    // Ref manual p.234 - ADC needs clock source
    dp.RCC.ccipr().write(|w| w.adcsel().sysclk());

    // ==== FLASH configuration ====
    // Flash memory clock is gated off during sleep and stop
    dp.RCC.ahb1smenr().write(|w| w.flashsmen().clear_bit());
    // Power down flash during sleep
    dp.FLASH.acr().write(|w| w.sleep_pd().set_bit());

    // ==== TIM6 configuration ====
    // GNSS pre-init delay
    dp.TIM6.psc().write(|w| w.psc().set(19999)); // 200kHz / (19999 + 1) = 10 Hz (100ms per tick)
    dp.TIM6.arr().write(|w| w.arr().set(4)); // Works at 400ms
    dp.TIM6.cr1().write(|w| w.urs().counter_only());
    dp.TIM6.egr().write(|w| w.ug().set_bit());
    dp.TIM6.dier().write(|w| w.uie().set_bit());

    // ==== GPIOA configuration ====
    // A0: ADC1 C5 | A2: VIN_DIV_EN
    // A15: DIO3
    // A4: NSS | A5: SCK | A6: MISO | A7: MOSI
    dp.GPIOA.moder().write(|w| {
        w.moder0()
            .analog()
            .moder2()
            .output()
            .moder4()
            .alternate()
            .moder5()
            .alternate()
            .moder6()
            .alternate()
            .moder7()
            .alternate()
            .moder15()
            .input()
    });
    dp.GPIOA.otyper().write(|w| w.ot2().open_drain());
    dp.GPIOA.bsrr().write(|w| w.bs2().set_bit());
    dp.GPIOA.pupdr().write(|w| w.pupdr4().pull_up());
    dp.GPIOA.afrl().write(|w| w.afrl4().af5().afrl5().af5().afrl6().af5().afrl7().af5());

    // ==== GPIOB configuration ====
    // B4: DIO1
    // B3: EN | B6: TX | B7: RX
    dp.GPIOB.moder().write(|w| w.moder3().output().moder4().input().moder6().alternate().moder7().alternate());
    dp.GPIOB.otyper().write(|w| w.ot3().push_pull());
    dp.GPIOB.bsrr().write(|w| w.br3().set_bit());
    dp.GPIOB.afrl().write(|w| w.afrl6().af7().afrl7().af7());

    // ==== DMA1 C2,C3 + SPI1 configuration ====
    // DMA channel selection p.299
    // C2: SPI1 RX
    // C3: SPI1 TX
    // C4: USART1 TX
    // C5: USART1 RX
    dp.DMA1.cselr().write(|w| w.c2s().map1().c3s().map1().c4s().map2().c5s().map2());

    // DMA C2 SPI1 RX
    dp.DMA1.ch2().par().write(|w| unsafe { w.pa().bits(SPI1_DR) });

    // DMA C3 SPI1 TX
    dp.DMA1.ch3().par().write(|w| unsafe { w.pa().bits(SPI1_DR) });

    dp.SPI1.cr2().write(|w| w.frxth().set_bit().ssoe().enabled().txdmaen().set_bit().rxdmaen().set_bit());

    // ==== DMA1 C4,C5 configuration ====
    // DMA C4 USART1 TX
    dp.DMA1.ch4().par().write(|w| unsafe { w.pa().bits(USART1_TDR) });
    dp.DMA1.ch4().mar().write(|w| unsafe { w.ma().bits(GNSS_SET_SENTENCE_OUTPUT.as_ptr() as u32) });

    // DMA C5 USART1 RX
    dp.DMA1.ch5().par().write(|w| unsafe { w.pa().bits(USART1_RDR) });
    dp.DMA1.ch5().mar().write(|w| unsafe { w.ma().bits(NMEA_BUFFER.get().as_ptr() as u32) });

    // ==== USART1 configuration ====
    dp.USART1.brr().write(|w| w.brr().set(21)); // 200khz / 9600 approx. 21
    dp.USART1.cr2().write(|w| w.add().set(b'\n')); // Character detection
    dp.USART1.cr3().write(|w| w.dmar().set_bit().dmat().set_bit());

    // ==== ADC1 configuration ====
    // Set 8-bit resolution
    dp.ADC1.cfgr().write(|w| w.res().bits8());
    // Set sequence length to 1, first conversion to channel 5
    dp.ADC1.sqr1().write(|w| unsafe { w.l().set(0).sq1().bits(5) });
    // Sample time = 2.5 ADC cycles (shortest)
    dp.ADC1.smpr1().write(|w| w.smp5().cycles2_5());
    dp.ADC1.ier().write(|w| w.adrdyie().set_bit().eocie().set_bit());

    // ==== EXTI configuration ====
    dp.SYSCFG.exticr2().write(|w| unsafe { w.exti4().bits(0b001) });
    dp.EXTI.rtsr1().write(|w| w.tr4().set_bit().tr15().set_bit().tr20().set_bit());
    dp.EXTI.imr1().write(|w| w.mr4().set_bit().mr15().set_bit().mr20().set_bit());

    // ==== PWR configuration ====
    unsafe {
        // Disable interrupt preemption?
        cp.SCB.aircr.write(0x05FA_0700);
        // Set SLEEPONEXIT
        cp.SCB.scr.write(SLEEPDEEP_OFF);
        // Set voltage scaling to range 2, low-power run mode and
        // remove write protection from BDCR and RTC registers
        dp.PWR.cr1().write(|w| w.vos().bits(2).lpr().set_bit().lpms().bits(1).dbp().set_bit());
    }

    // ==== RTC configuration ====
    // Configure RTC, set periodic wake up
    while dp.RCC.csr().read().lsirdy().bit_is_clear() {}
    dp.RCC.bdcr().write(|w| w.rtcsel().lsi().rtcen().set_bit());
    // Remove write protection from RTC registers
    dp.RTC.wpr().write(|w| w.key().deactivate1());
    dp.RTC.wpr().write(|w| w.key().deactivate2());
    // Enter init mode to set prescaler values
    dp.RTC.icsr().write(|w| w.init().set_bit());
    while dp.RTC.icsr().read().initf().bit_is_clear() {}
    // AN4759 p.12 - calendar unit = 1 Hz
    dp.RTC.prer().write(|w| w.prediv_a().set(127).prediv_s().set(249));
    dp.RTC.icsr().write(|w| w.init().clear_bit());
    // Turn off wake-up timer
    dp.RTC.cr().write(|w| w.wute().clear_bit());
    while dp.RTC.icsr().read().wutwf().bit_is_clear() {}
    // Write wake-up timer registers
    dp.RTC.wutr().write(|w| w.wut().set(WAKEUP_INTERVAL - 1));

    let commands = COMMANDS.get_mut();

    unsafe {
        sx126x::WRITE_PACKET.0.transfer_length = 5;

        commands.enqueue(&sx126x::SET_PACKET_TYPE);
        commands.enqueue(&sx126x::SET_RF_FREQUENCY);
        commands.enqueue(&sx126x::SET_BUFFER_ADDRESS);
        commands.enqueue(&sx126x::WRITE_SYNC_WORD);
        commands.enqueue(&sx126x::SET_MOD_PARAMS);
        commands.enqueue(&sx126x::SET_REG_MODE);
        commands.enqueue(&sx126x::SET_CAD_PARAMS);
        commands.enqueue(&sx126x::WRITE_PACKET);
        commands.enqueue(&sx126x::SET_PACKET_PARAMS);
        commands.enqueue(&sx126x::SET_DIO2_AS_RF_SWITCH_CTRL);
        commands.enqueue(&sx126x::UNMASK_CAD);

        // Unmask NVIC global interrupts
        cortex_m::peripheral::NVIC::unmask(Interrupt::ADC1_2); // EOC, ADRDY
        cortex_m::peripheral::NVIC::unmask(Interrupt::TIM6_DACUNDER); // UIF - GNSS pre-init delay
        cortex_m::peripheral::NVIC::unmask(Interrupt::DMA1_CHANNEL2); // TC - SPI1 RX
        cortex_m::peripheral::NVIC::unmask(Interrupt::DMA1_CHANNEL3); // TC - SPI1 TX
        cortex_m::peripheral::NVIC::unmask(Interrupt::USART1); // CM
        cortex_m::peripheral::NVIC::unmask(Interrupt::EXTI4); // DIO1 RT
        cortex_m::peripheral::NVIC::unmask(Interrupt::EXTI15_10); // DIO3 RT
        cortex_m::peripheral::NVIC::unmask(Interrupt::RTC_WKUP); // WUTE
        cortex_m::peripheral::NVIC::unmask(Interrupt::DMA1_CHANNEL4); // TC - USART1 TX
    }

    // Initialize SX1268
    dp.RTC.cr().write(|w| w.wucksel().clock_spare().wutie().set_bit().wute().set_bit());
    send_command(&sx126x::SET_STANDBY, dp);

    loop {
        unsafe { asm!("wfi") };
    }
}

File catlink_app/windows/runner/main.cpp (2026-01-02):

#include <flutter/dart_project.h>
#include <flutter/flutter_view_controller.h>
#include <windows.h>

#include "flutter_window.h"
#include "utils.h"

int APIENTRY wWinMain(_In_ HINSTANCE instance, _In_opt_ HINSTANCE prev,
                      _In_ wchar_t *command_line, _In_ int show_command) {
  // Attach to console when present (e.g., 'flutter run') or create a
  // new console when running with a debugger.
  if (!::AttachConsole(ATTACH_PARENT_PROCESS) && ::IsDebuggerPresent()) {
    CreateAndAttachConsole();
  }

  // Initialize COM, so that it is available for use in the library and/or
  // plugins.
  ::CoInitializeEx(nullptr, COINIT_APARTMENTTHREADED);

  flutter::DartProject project(L"data");

  std::vector<std::string> command_line_arguments =
      GetCommandLineArguments();

  project.set_dart_entrypoint_arguments(std::move(command_line_arguments));

  FlutterWindow window(project);
  Win32Window::Point origin(10, 10);
  Win32Window::Size size(1280, 720);
  if (!window.Create(L"catlink_app", origin, size)) {
    return EXIT_FAILURE;
  }
  window.SetQuitOnClose(true);

  ::MSG msg;
  while (::GetMessage(&msg, nullptr, 0, 0)) {
    ::TranslateMessage(&msg);
    ::DispatchMessage(&msg);
  }

  ::CoUninitialize();
  return EXIT_SUCCESS;
}

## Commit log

2025-10-21 Changed logo, added pin 1 silkscreen for ESD diode
    [catlink-tracker-pcb.kicad_pcb]
2025-10-21 Add BoM for tracker
    [catlink-tracker-pcb.csv]
2025-12-21 Added state LED and IO9 switch
    [catlink-gateway-pcb-eval.kicad_pcb, catlink-gateway-pcb-eval.kicad_sch]
2025-12-21 Tracker pcb production, gateway eval v0.2 production
    [catlink-gateway-pcb-eval.csv, catlink-gateway-pcb-eval.kicad_sch, catlink-tracker-pcb.csv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]
2026-01-02 Idle disconnect based on subscriptions, fix oneplus disconnect bug
    [ble.c]
2026-02-20 Gateway firmware: fix RSSI overflow, and undivide vbat
    [ble.c, lora.c]
2026-02-22 Add enclosure 3D models
    [battery14500.FCStd, lora_antenna.FCStd, pcb.FCStd]
2026-02-22 Gateway enclosure
    [gateway.FCStd]
2026-02-27 Power measurement plots
